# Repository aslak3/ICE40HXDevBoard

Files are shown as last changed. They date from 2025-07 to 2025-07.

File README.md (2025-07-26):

# ICE40HXDevBoard: an expandable iCE40HX4K development board

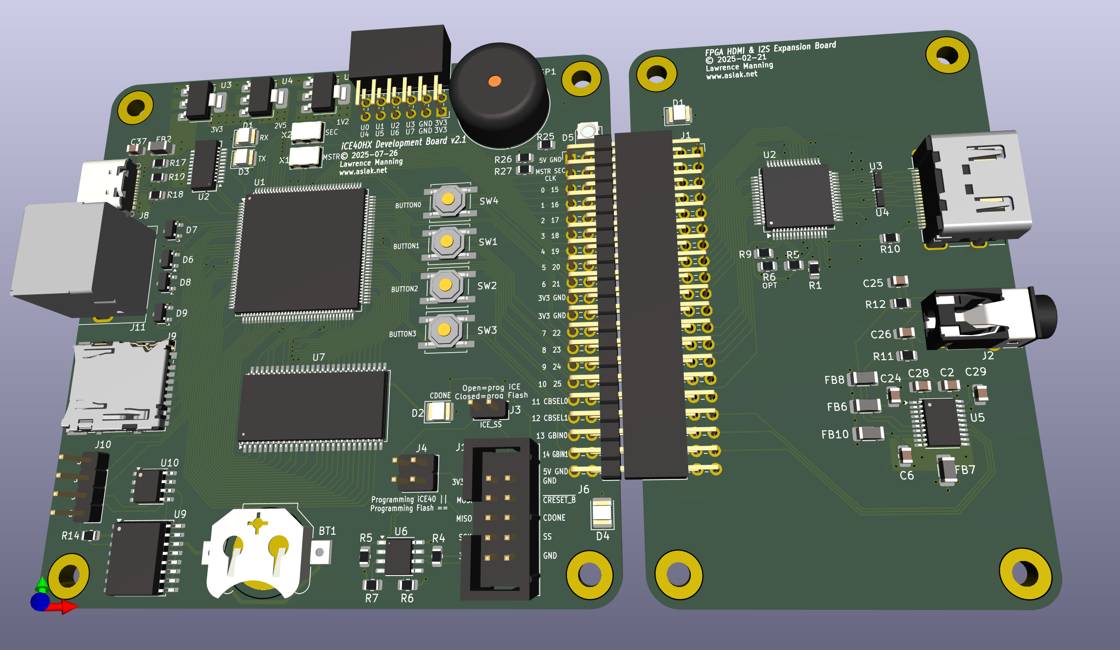
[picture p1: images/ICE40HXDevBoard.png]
ICE40HXDevBoard PCB


## Features

The specification for this development board is as follows:

* [iCE40HX4K](https://www.latticesemi.com/view_document?document_id=49312) in
144 pin QFP
  * [N25Q032A](https://docs.rs-online.com/0866/0900766b80f7f8ab.pdf) 32 Mbit SPI flash
* Space for two 5mm x 3mm oscillators
* [W9825G6KH](https://www.mouser.co.uk/datasheet/2/949/w9825g6kh_a04-1489735.pdf) 4M x 4 Banks x 16 bits SDRAM (32 MByte)
* PS/2 port with two channels for a mouse and keyboard
* I2C:
  * [DS3231M](https://www.analog.com/media/en/technical-documentation/data-sheets/ds3231m.pdf) RTC
  * [AT24C64](https://ww1.microchip.com/downloads/en/devicedoc/doc0336.pdf) EEPROM
  * Header for I2C connections
* RGB LED
* 4 buttons
* Buzzer
* [FT231XS](https://ftdichip.com/wp-content/uploads/2024/05/DS_FT231X.pdf) USB to UART converter with USB-C socket doubling up as the source of 5V power
* [MicroSDCard](https://en.wikipedia.org/wiki/SD_card) slot
* [PMOD](https://en.wikipedia.org/wiki/Pmod_Interface) header
* 40 pin expansion:
  * 3.3V and 5V power, 27 general purpose IO, 2 clock pins, shared I2C bus

A [schematic](ICE40HXDevBoard.pdf) is included here, along with the
[KiCAD](https://www.kicad.org) data files, whcih are in KiCAD 6 format.

## HDMI expansion card features

An expansion card featuring HDMI and I2S output on a 3.5mm jack has been built:

* [TFP410PAP](https://www.ti.com/lit/ds/symlink/tfp410.pdf) HDMI transmitter
  * Full size HDMI connector
* [PCM5100A](https://www.ti.com/lit/ds/symlink/pcm5100a.pdf) I2S DAC
  * 3.5mm stereo jack

## VGA expansion card features

A further, unbuilt, expansion card has been designed for VGA output:

* [ADV7123](https://www.analog.com/media/en/technical-documentation/data-sheets/ADV7123.pdf) RGB DAC
* [PCM5100A](https://www.ti.com/lit/ds/symlink/pcm5100a.pdf) I2S DAC
  * 3.5mm stereo jack

## PCB design

The PCBs are 4 layer boards.  My boards were manufactured by
[JLCPCB](https://www.jlcpcb.com).

## Using

The jumper mechanism to route the SPI signals which carry the configuration data
from the programmer was borrowed directly from the [Lattice’s iCE40 UltraPlus
Breakout Board](https://www.latticesemi.com/view_document?document_id=51987).

Any iCE40 compatible programmer should be useable. I built my own, out of a Pi
Pico, the software for which is documented in [another
repo](https://github.com/aslak3/spi-flasher). The programmer has been used to
program both the attached flash and the FPGA directly.

The header is a IDC10 in 100mil pitch. For the pinout refer to the schematic.

## Possible gotchas

The design of the FPGA board is a tweaked version of the build I have on my bench, since it has some issues:

* The PMOD pinning was backwards.
* The PS/2 port lacked clamping diodes due to the FPGA's intolerance of 5V signals from the PS/2 device. Remarkably I see no problems with my board, but it is not correct not having diodes to clamp the PS/2 data and clock lines to 3.3V.

The following features have not been tested yet:

* The MicroSDCard slot
* The SDRAM
* The I2C RTC
* The I2S DAC

## Blog

The best place to learn about this board is undoubtably [my
blog](https://www.aslak.net/).

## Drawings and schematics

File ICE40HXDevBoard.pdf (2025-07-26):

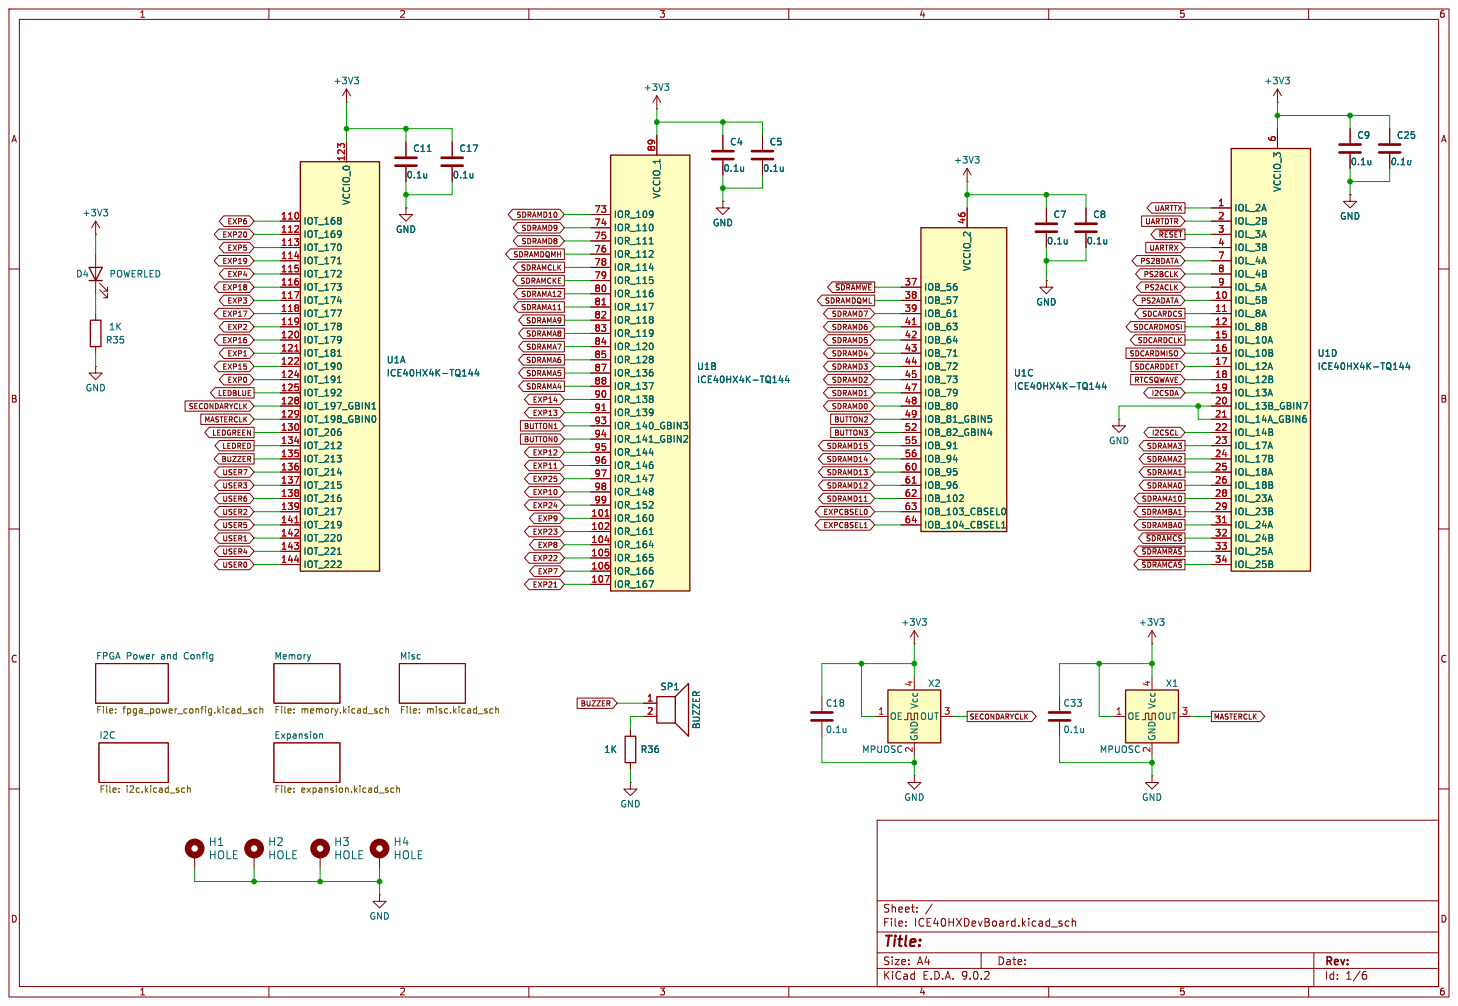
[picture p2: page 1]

Id: 1/6 Title: File: ICE40HXDevBoard.kicad_sch Sheet: / FPGA Power and Config File: fpga_power_config.kicad_sch

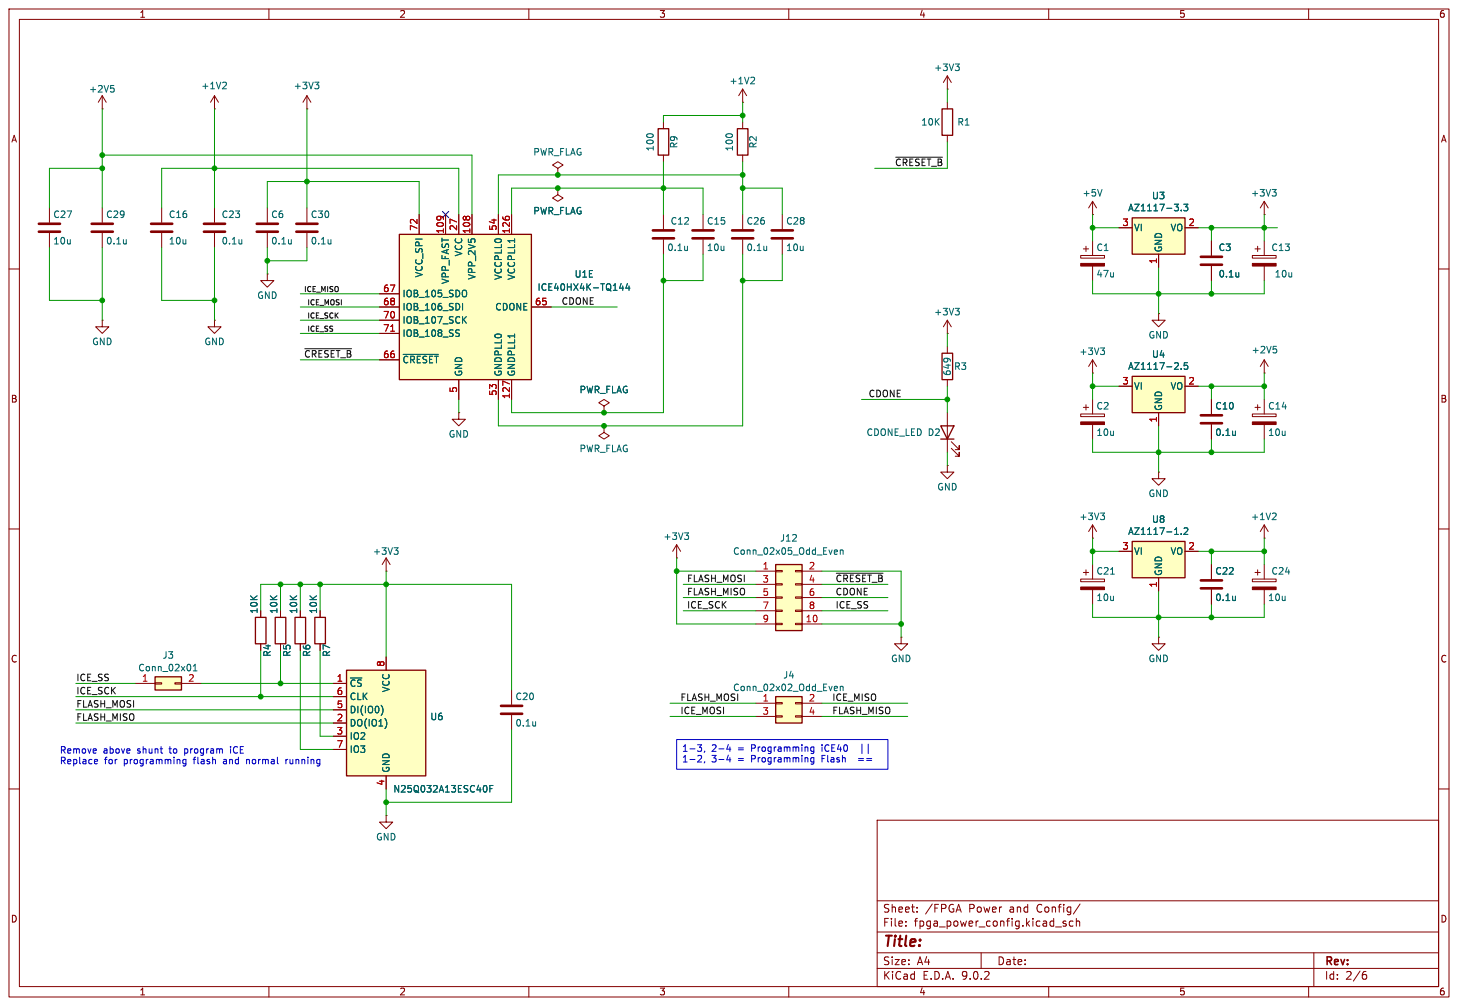
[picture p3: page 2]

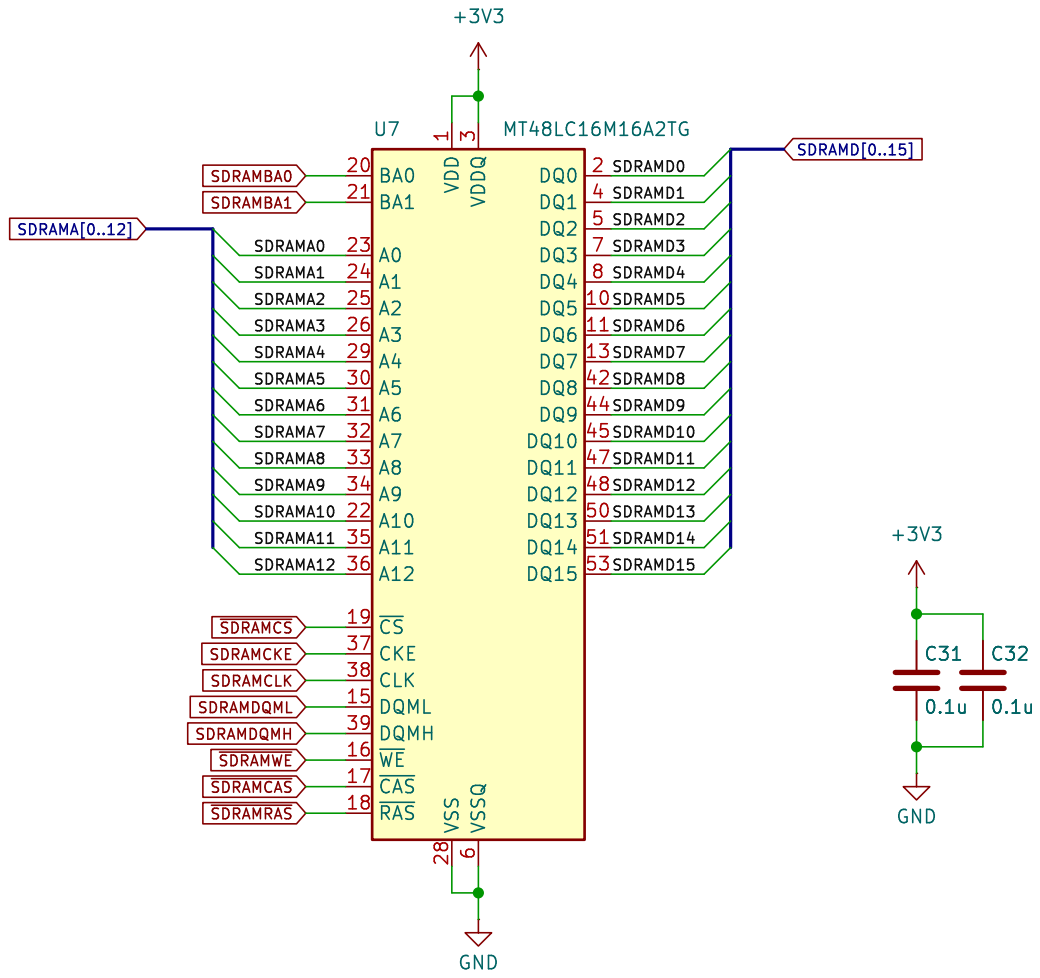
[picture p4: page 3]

SDRAMBA1 SDRAMBA0 SDRAMDQML ~{SDRAMCAS} ~{SDRAMWE} ~{SDRAMRAS} SDRAMDQMH

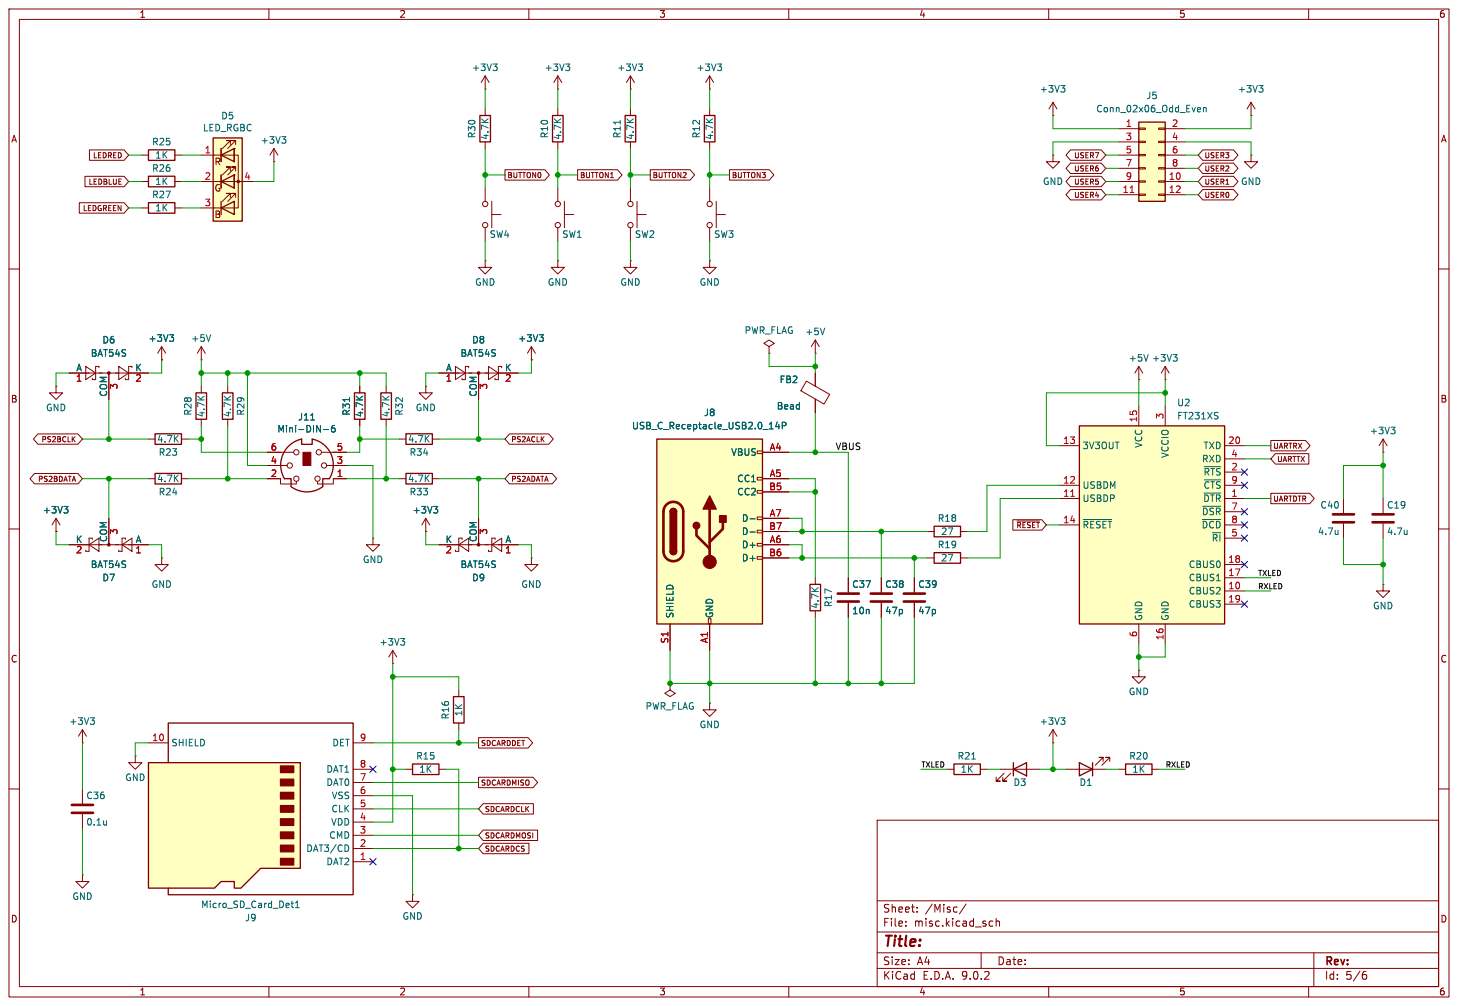
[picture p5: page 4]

3 GND 16 TXD 20 RXD 4 ~{RTS}2 ~{CTS}9 ~{DTR}1 ~{DSR}7 ~{DCD}8 ~{RI}5 CBUS0 18 CBUS1 17 CBUS2 10 CBUS3 19 U2 FT231XS R15

Id: 5/6 Title: File: misc.kicad_sch Sheet: /Misc/

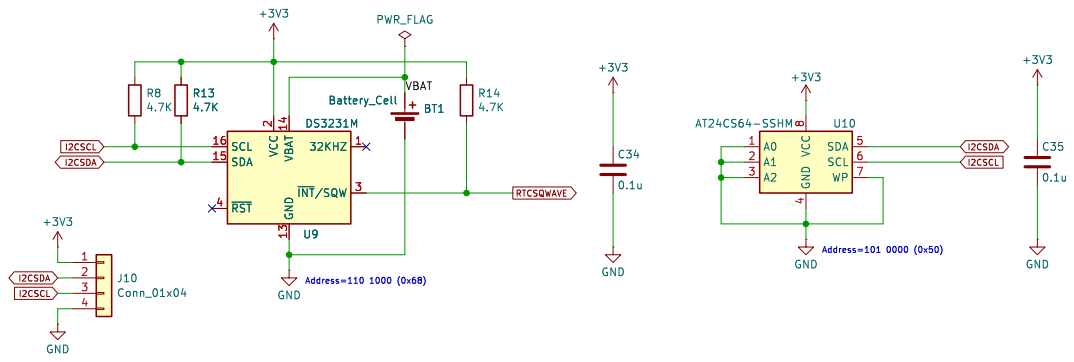
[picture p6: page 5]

4 SDA 5 SCL 6 WP 7 AT24CS64-SSHM U10 BT1 Battery_Cell PWR_FLAG

Id: 6/6 Title: File: i2c.kicad_sch Sheet: /I2C/

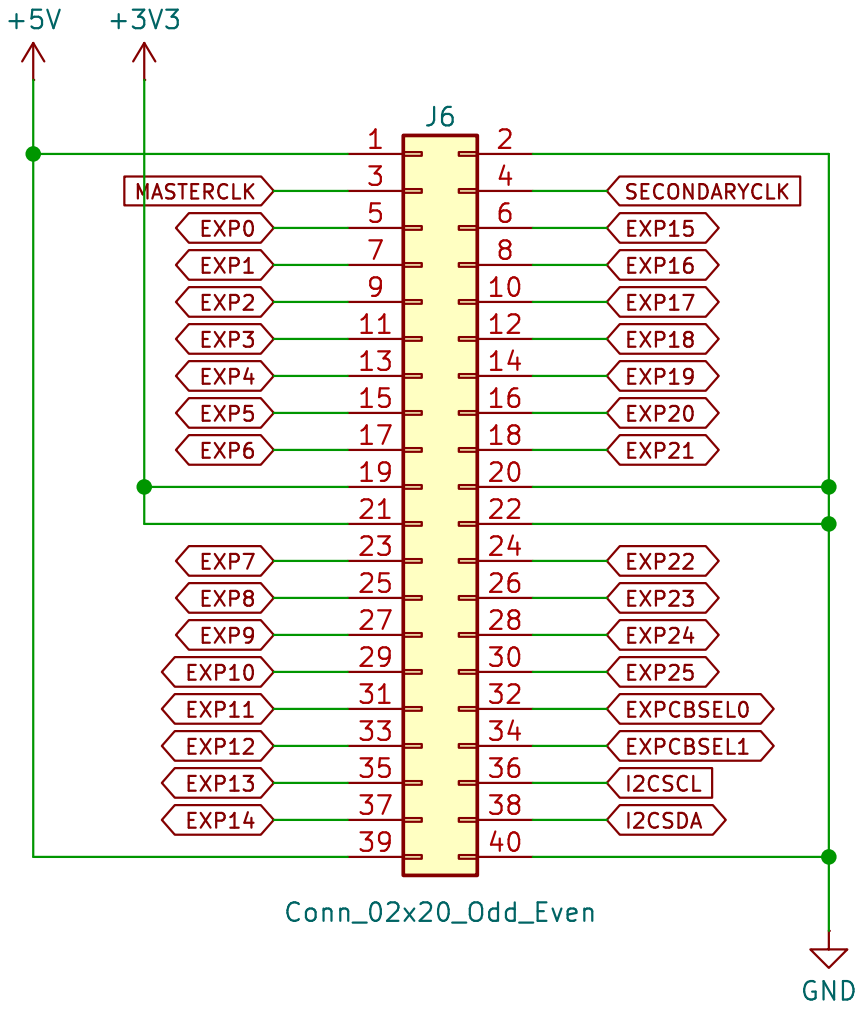
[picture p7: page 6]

Id: 6/6 Title: File: expansion.kicad_sch Sheet: /Expansion/

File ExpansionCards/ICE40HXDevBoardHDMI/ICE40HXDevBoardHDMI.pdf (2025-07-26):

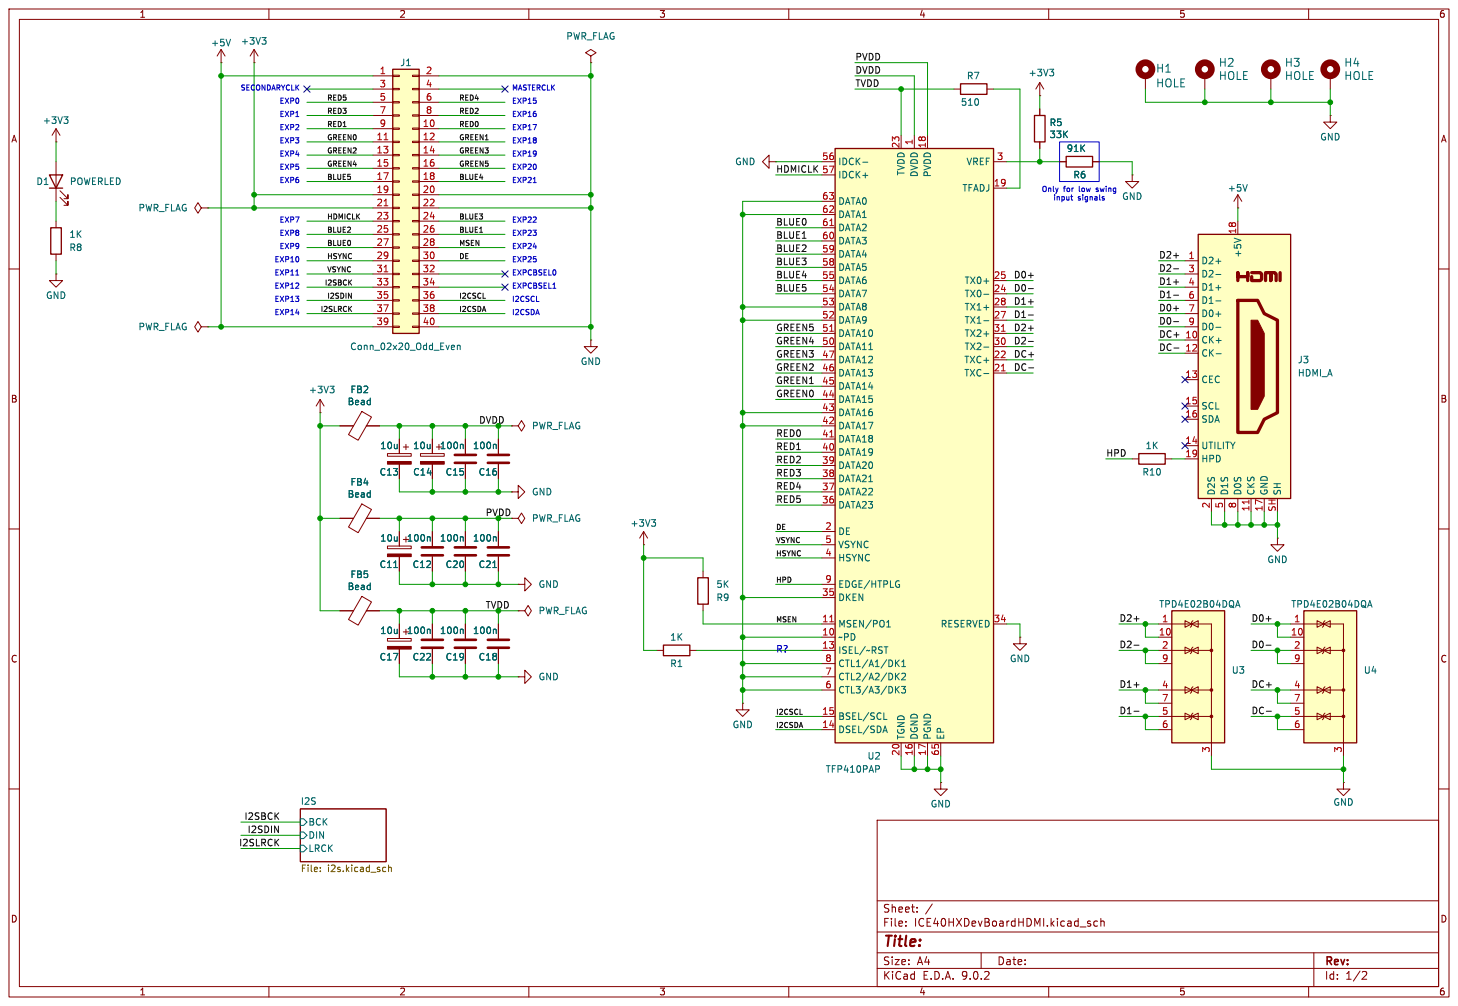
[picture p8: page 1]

1 DGND 16 PVDD 18 PGND 17 EP 65 VREF 3 TFADJ 19 TX0+ 25 TX0- 24 TX1+ 28 TX1- 27 TX2+ 31 TX2- 30 TXC+ 22 TXC- 21 RESERVED 34 U2 TFP410PAP

8 CKS 11 GND 17 SH SH

Id: 1/2 Title: File: ICE40HXDevBoardHDMI.kicad_sch Sheet: / BCK DIN

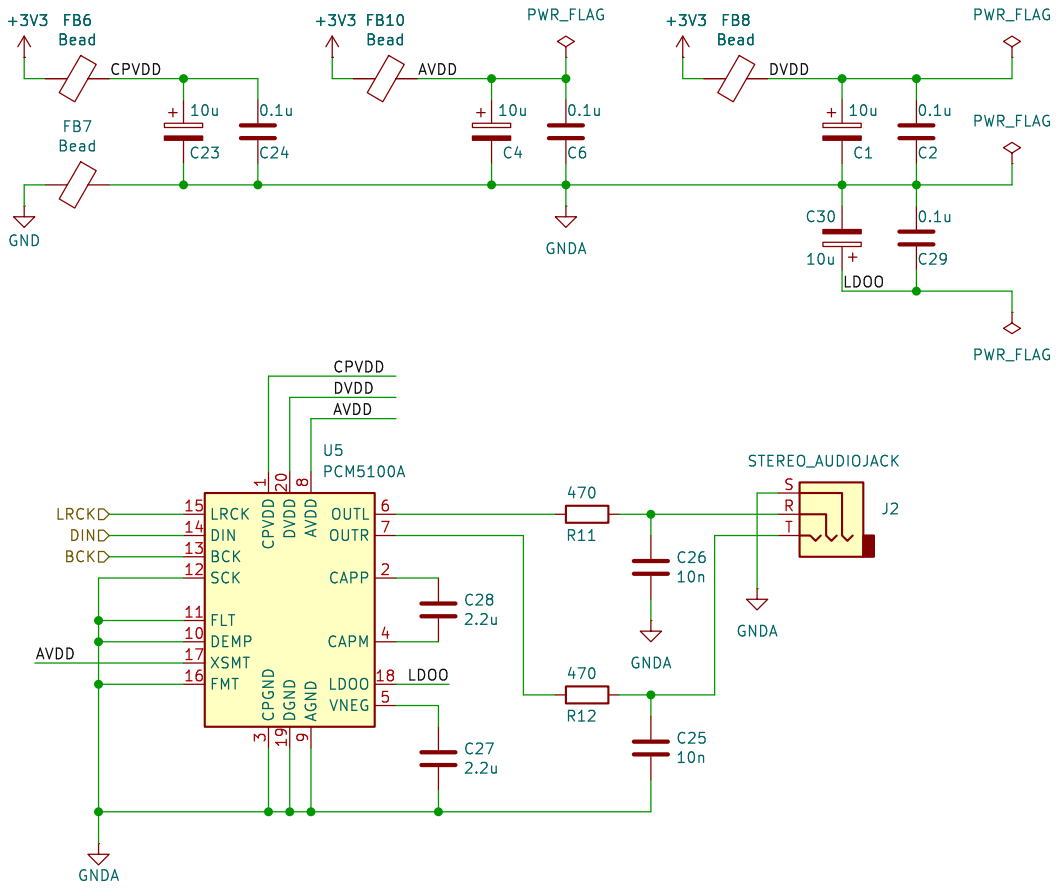
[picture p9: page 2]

9 OUTL 6 OUTR 7 CAPP 2 CAPM 4

Id: 2/2 Title: File: i2s.kicad_sch Sheet: /I2S/

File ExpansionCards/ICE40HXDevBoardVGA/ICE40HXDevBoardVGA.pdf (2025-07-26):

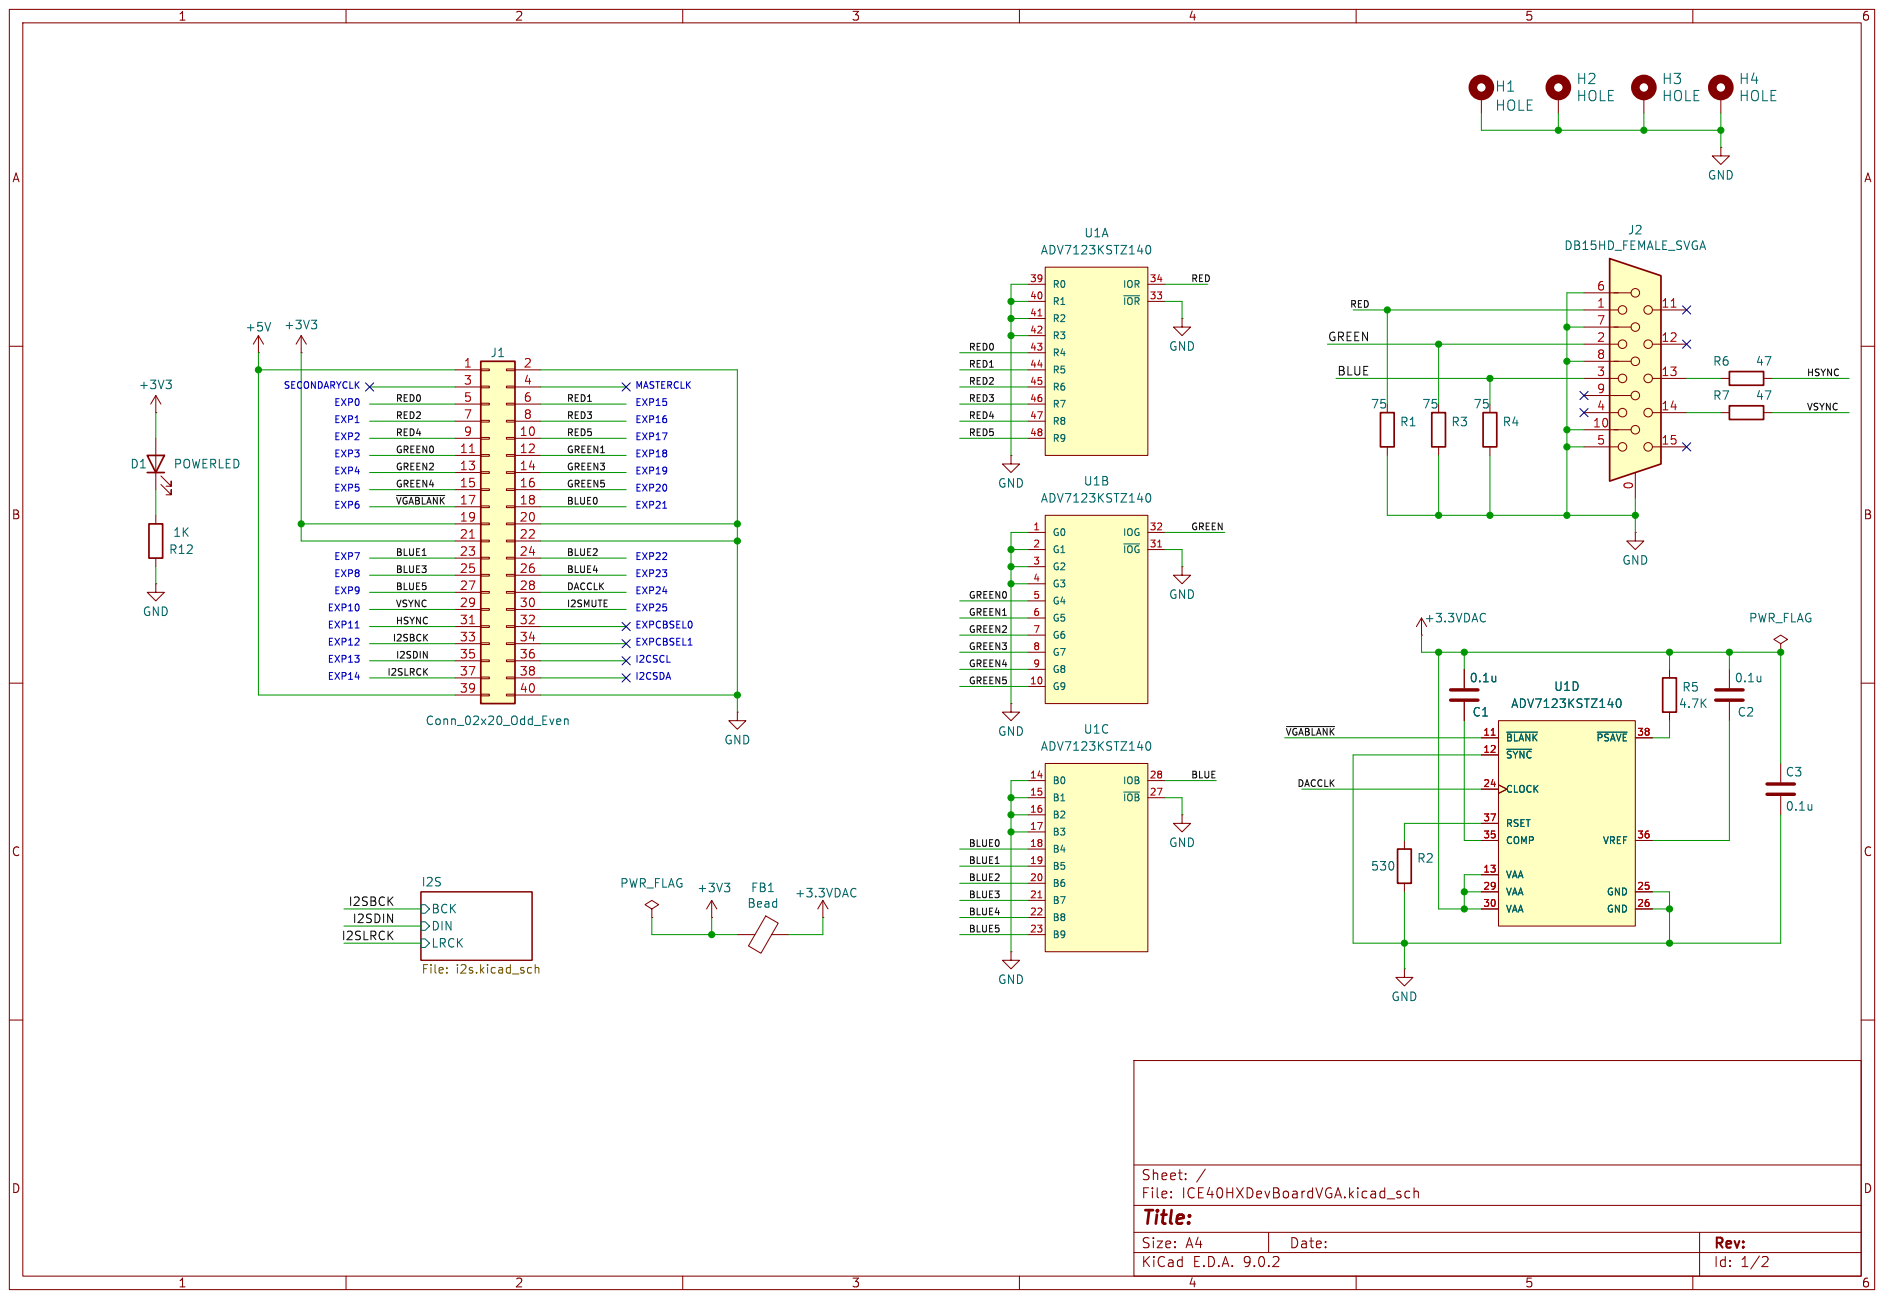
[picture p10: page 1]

Id: 1/2 Title: File: ICE40HXDevBoardVGA.kicad_sch Sheet: / BCK DIN

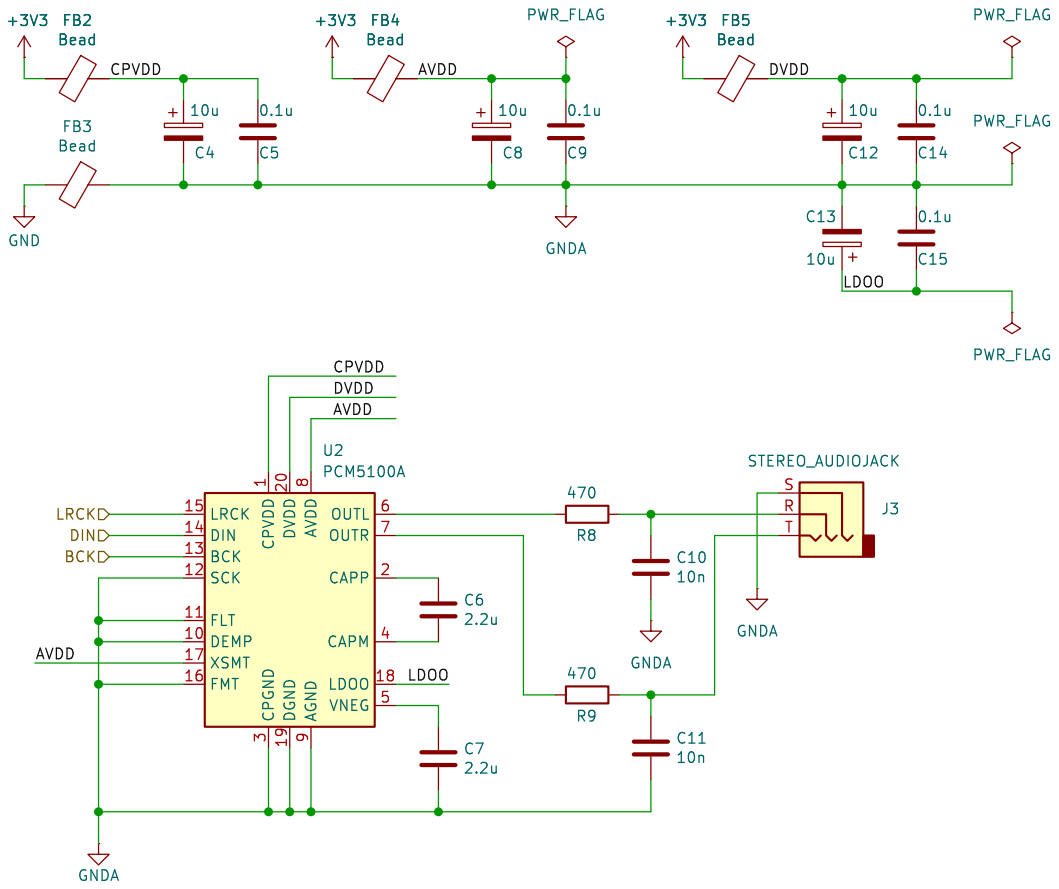
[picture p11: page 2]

9 OUTL 6 OUTR 7 CAPP 2 CAPM 4

Id: 2/2 Title: File: i2s.kicad_sch Sheet: /I2S/

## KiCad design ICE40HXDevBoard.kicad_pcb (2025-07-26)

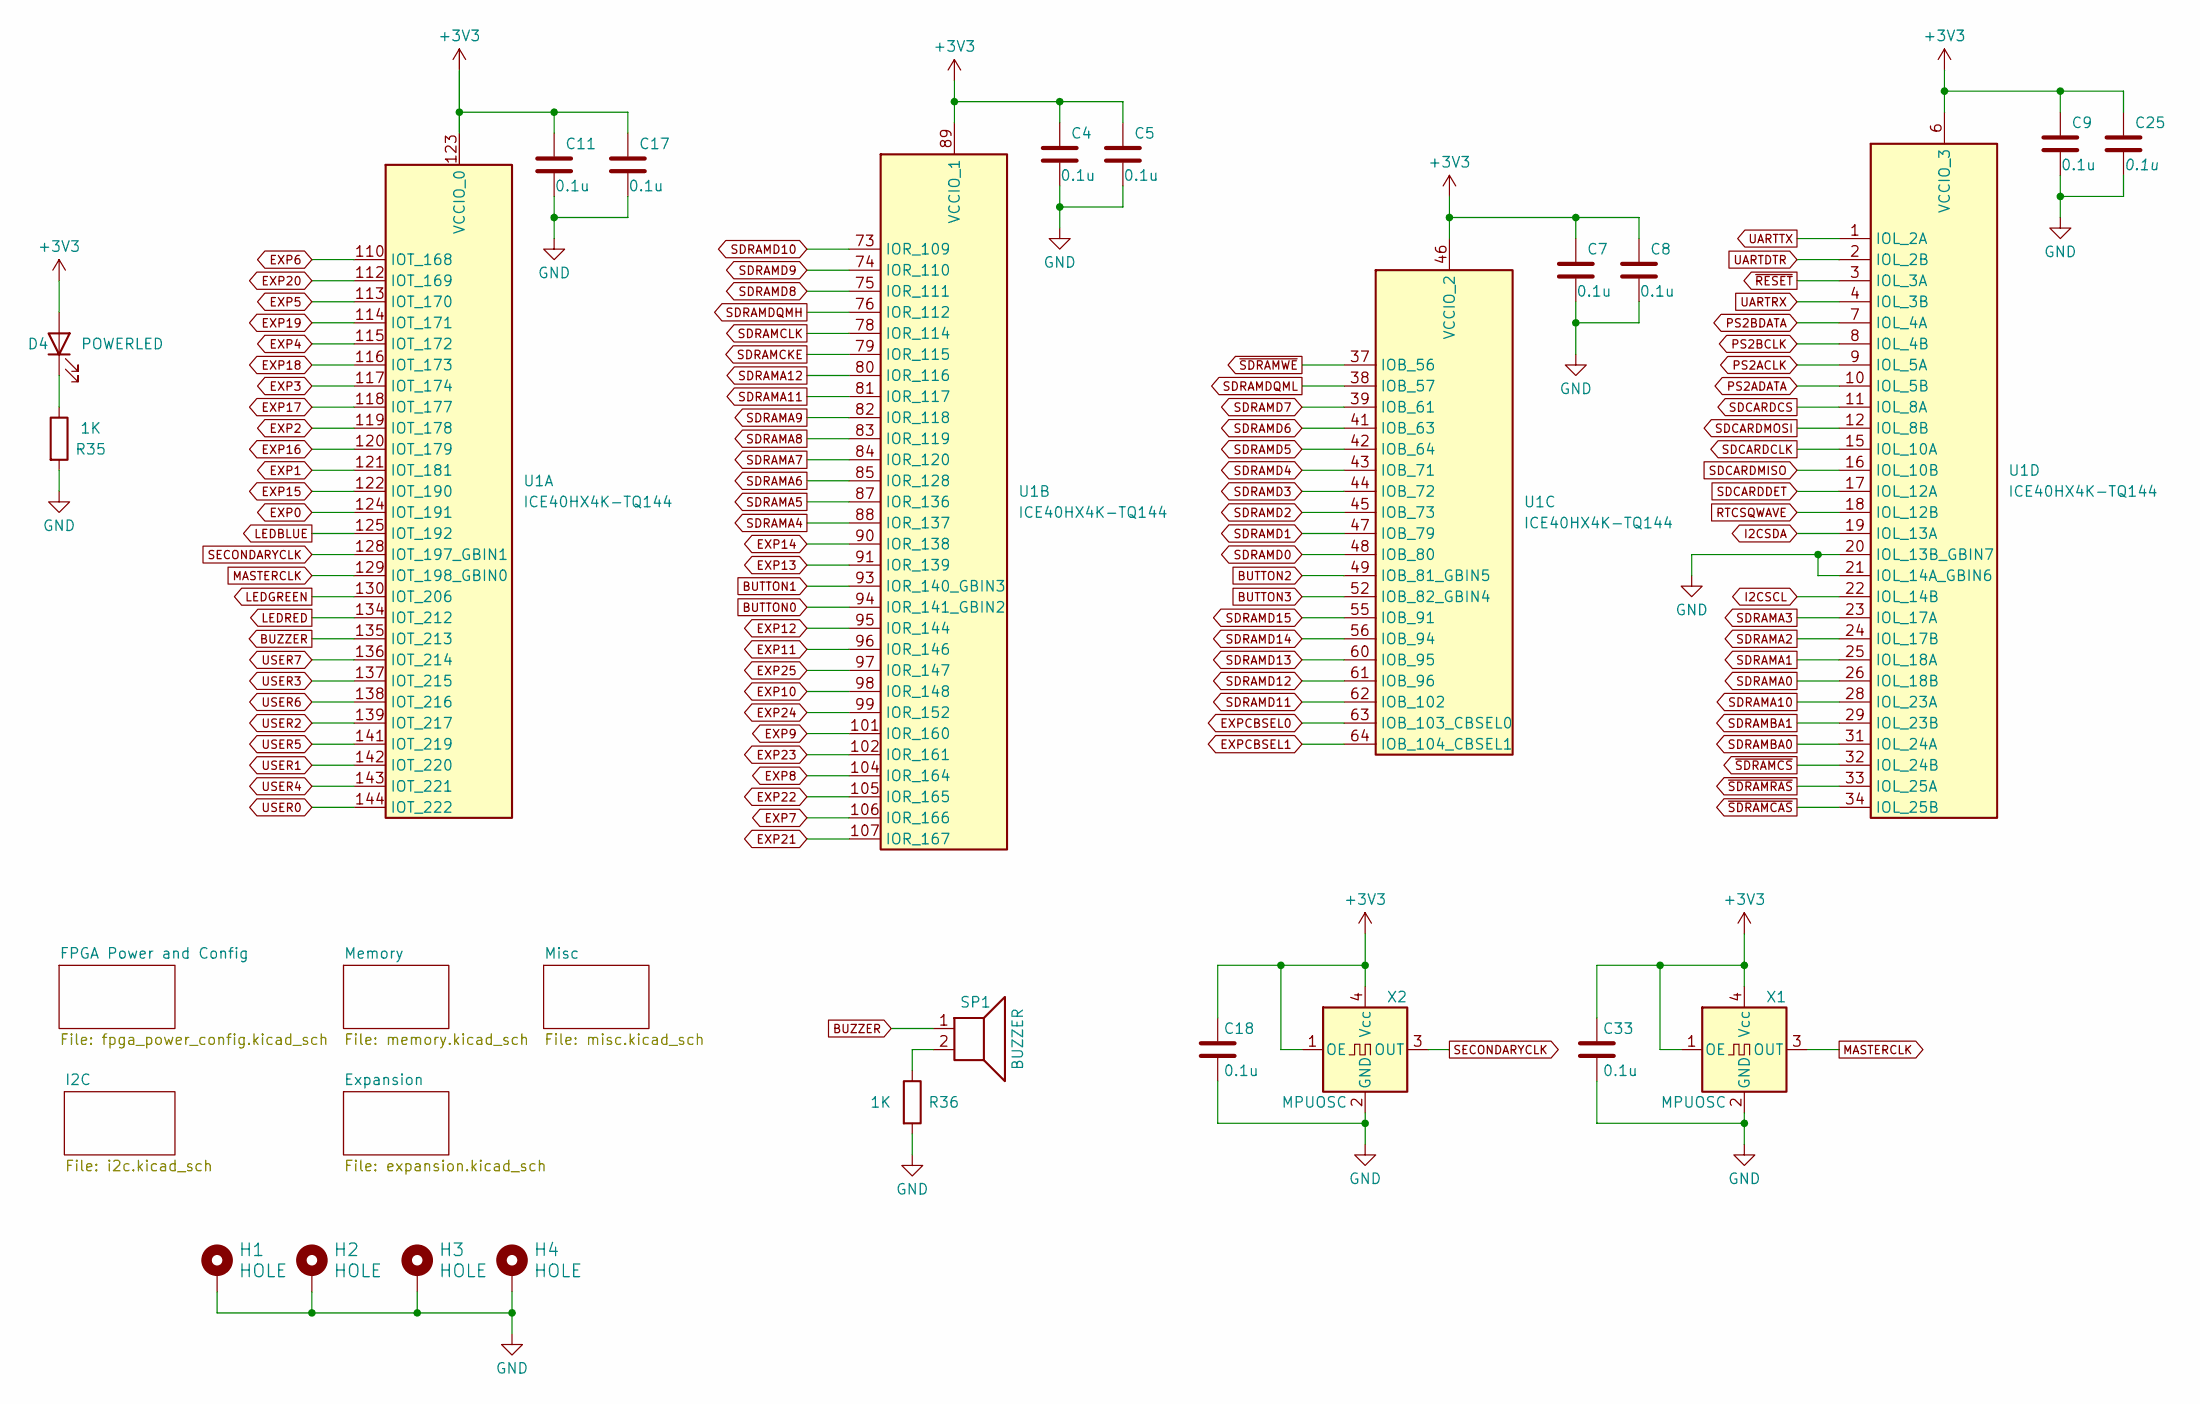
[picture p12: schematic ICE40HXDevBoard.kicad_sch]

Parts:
C4, C5, C7, C8, C9, C11, C17, C18, C25, C33: 0.1u; C_0805_2012Metric
D4: POWERLED; LED_1210_3225Metric
H1, H2, H3, H4: HOLE; MountingHole_3.2mm_M3_Pad
R35, R36: 1K; R_0805_2012Metric
SP1: BUZZER; Buzzer_15x7.5RM7.6
U1: ICE40HX4K-TQ144; TQFP-144_20x20mm_P0.5mm
X1, X2: MPUOSC; Oscillator_SMD_SeikoEpson_SG8002LB-4Pin_5.0x3.2mm

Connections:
+3V3: C4.1, C5.1, C7.1, C8.1, C9.1, C11.1, C17.1, C18.1, C25.1, C33.1, D4.2 (A), U1.6 (VCCIO_3), U1.30 (VCCIO_3), U1.46 (VCCIO_2), U1.57 (VCCIO_2), U1.89 (VCCIO_1), U1.100 (VCCIO_1), U1.123 (VCCIO_0), U1.131 (VCCIO_0), X1.1 (OE), X1.4 (Vcc), X2.1 (OE), X2.4 (Vcc); also elsewhere on the board
BUTTON0: U1.94 (IOR_141_GBIN2); also elsewhere on the board
BUTTON1: U1.93 (IOR_140_GBIN3); also elsewhere on the board
BUTTON2: U1.49 (IOB_81_GBIN5); also elsewhere on the board
BUTTON3: U1.52 (IOB_82_GBIN4); also elsewhere on the board
BUZZER: SP1.1, U1.135 (IOT_213)
EXP0: U1.124 (IOT_191); also elsewhere on the board
EXP1: U1.121 (IOT_181); also elsewhere on the board
EXP2: U1.119 (IOT_178); also elsewhere on the board
EXP3: U1.117 (IOT_174); also elsewhere on the board
EXP4: U1.115 (IOT_172); also elsewhere on the board
EXP5: U1.113 (IOT_170); also elsewhere on the board
EXP6: U1.110 (IOT_168); also elsewhere on the board
EXP7: U1.106 (IOR_166); also elsewhere on the board
EXP8: U1.104 (IOR_164); also elsewhere on the board
EXP9: U1.101 (IOR_160); also elsewhere on the board
EXP10: U1.98 (IOR_148); also elsewhere on the board
EXP11: U1.96 (IOR_146); also elsewhere on the board
EXP12: U1.95 (IOR_144); also elsewhere on the board
EXP13: U1.91 (IOR_139); also elsewhere on the board
EXP14: U1.90 (IOR_138); also elsewhere on the board
EXP15: U1.122 (IOT_190); also elsewhere on the board
EXP16: U1.120 (IOT_179); also elsewhere on the board
EXP17: U1.118 (IOT_177); also elsewhere on the board
EXP18: U1.116 (IOT_173); also elsewhere on the board
EXP19: U1.114 (IOT_171); also elsewhere on the board
EXP20: U1.112 (IOT_169); also elsewhere on the board
EXP21: U1.107 (IOR_167); also elsewhere on the board
EXP22: U1.105 (IOR_165); also elsewhere on the board
EXP23: U1.102 (IOR_161); also elsewhere on the board
EXP24: U1.99 (IOR_152); also elsewhere on the board
EXP25: U1.97 (IOR_147); also elsewhere on the board
EXPCBSEL0: U1.63 (IOB_103_CBSEL0); also elsewhere on the board
EXPCBSEL1: U1.64 (IOB_104_CBSEL1); also elsewhere on the board
GND: C4.2, C5.2, C7.2, C8.2, C9.2, C11.2, C17.2, C18.2, C25.2, C33.2, H1.1, H2.1, H3.1, H4.1, R35.2, R36.2, U1.20 (IOL_13B_GBIN7), U1.21 (IOL_14A_GBIN6), X1.2 (GND), X2.2 (GND); also elsewhere on the board
I2CSCL: U1.22 (IOL_14B); also elsewhere on the board
I2CSDA: U1.19 (IOL_13A); also elsewhere on the board
LEDBLUE: U1.125 (IOT_192); also elsewhere on the board
LEDGREEN: U1.130 (IOT_206); also elsewhere on the board
LEDRED: U1.134 (IOT_212); also elsewhere on the board
MASTERCLK: U1.129 (IOT_198_GBIN0), X1.3 (OUT); also elsewhere on the board
unnamed: D4.1 (K), R35.1
unnamed: R36.1, SP1.2
PS2ACLK: U1.9 (IOL_5A); also elsewhere on the board
PS2ADATA: U1.10 (IOL_5B); also elsewhere on the board
PS2BCLK: U1.8 (IOL_4B); also elsewhere on the board
PS2BDATA: U1.7 (IOL_4A); also elsewhere on the board
RTCSQWAVE: U1.18 (IOL_12B); also elsewhere on the board
SDCARDCLK: U1.15 (IOL_10A); also elsewhere on the board
SDCARDCS: U1.11 (IOL_8A); also elsewhere on the board
SDCARDDET: U1.17 (IOL_12A); also elsewhere on the board
SDCARDMISO: U1.16 (IOL_10B); also elsewhere on the board
SDCARDMOSI: U1.12 (IOL_8B); also elsewhere on the board
SDRAMA0: U1.26 (IOL_18B); also elsewhere on the board
SDRAMA1: U1.25 (IOL_18A); also elsewhere on the board
SDRAMA2: U1.24 (IOL_17B); also elsewhere on the board
SDRAMA3: U1.23 (IOL_17A); also elsewhere on the board
SDRAMA4: U1.88 (IOR_137); also elsewhere on the board
SDRAMA5: U1.87 (IOR_136); also elsewhere on the board
SDRAMA6: U1.85 (IOR_128); also elsewhere on the board
SDRAMA7: U1.84 (IOR_120); also elsewhere on the board
SDRAMA8: U1.83 (IOR_119); also elsewhere on the board
SDRAMA9: U1.82 (IOR_118); also elsewhere on the board
SDRAMA10: U1.28 (IOL_23A); also elsewhere on the board
SDRAMA11: U1.81 (IOR_117); also elsewhere on the board
SDRAMA12: U1.80 (IOR_116); also elsewhere on the board
SDRAMBA0: U1.31 (IOL_24A); also elsewhere on the board
SDRAMBA1: U1.29 (IOL_23B); also elsewhere on the board
SDRAMCKE: U1.79 (IOR_115); also elsewhere on the board
SDRAMCLK: U1.78 (IOR_114); also elsewhere on the board
SDRAMD0: U1.48 (IOB_80); also elsewhere on the board
SDRAMD1: U1.47 (IOB_79); also elsewhere on the board
SDRAMD2: U1.45 (IOB_73); also elsewhere on the board
SDRAMD3: U1.44 (IOB_72); also elsewhere on the board
SDRAMD4: U1.43 (IOB_71); also elsewhere on the board
SDRAMD5: U1.42 (IOB_64); also elsewhere on the board
SDRAMD6: U1.41 (IOB_63); also elsewhere on the board
SDRAMD7: U1.39 (IOB_61); also elsewhere on the board
SDRAMD8: U1.75 (IOR_111); also elsewhere on the board
SDRAMD9: U1.74 (IOR_110); also elsewhere on the board
SDRAMD10: U1.73 (IOR_109); also elsewhere on the board
SDRAMD11: U1.62 (IOB_102); also elsewhere on the board
SDRAMD12: U1.61 (IOB_96); also elsewhere on the board
SDRAMD13: U1.60 (IOB_95); also elsewhere on the board
SDRAMD14: U1.56 (IOB_94); also elsewhere on the board
SDRAMD15: U1.55 (IOB_91); also elsewhere on the board
SDRAMDQMH: U1.76 (IOR_112); also elsewhere on the board
SDRAMDQML: U1.38 (IOB_57); also elsewhere on the board
SECONDARYCLK: U1.128 (IOT_197_GBIN1), X2.3 (OUT); also elsewhere on the board
UARTDTR: U1.2 (IOL_2B); also elsewhere on the board
UARTRX: U1.4 (IOL_3B); also elsewhere on the board
UARTTX: U1.1 (IOL_2A); also elsewhere on the board
USER0: U1.144 (IOT_222); also elsewhere on the board
USER1: U1.142 (IOT_220); also elsewhere on the board
USER2: U1.139 (IOT_217); also elsewhere on the board
USER3: U1.137 (IOT_215); also elsewhere on the board
USER4: U1.143 (IOT_221); also elsewhere on the board
USER5: U1.141 (IOT_219); also elsewhere on the board
USER6: U1.138 (IOT_216); also elsewhere on the board
USER7: U1.136 (IOT_214); also elsewhere on the board
~RESET: U1.3 (IOL_3A); also elsewhere on the board
~SDRAMCAS: U1.34 (IOL_25B); also elsewhere on the board
~SDRAMCS: U1.32 (IOL_24B); also elsewhere on the board
~SDRAMRAS: U1.33 (IOL_25A); also elsewhere on the board
~SDRAMWE: U1.37 (IOB_56); also elsewhere on the board

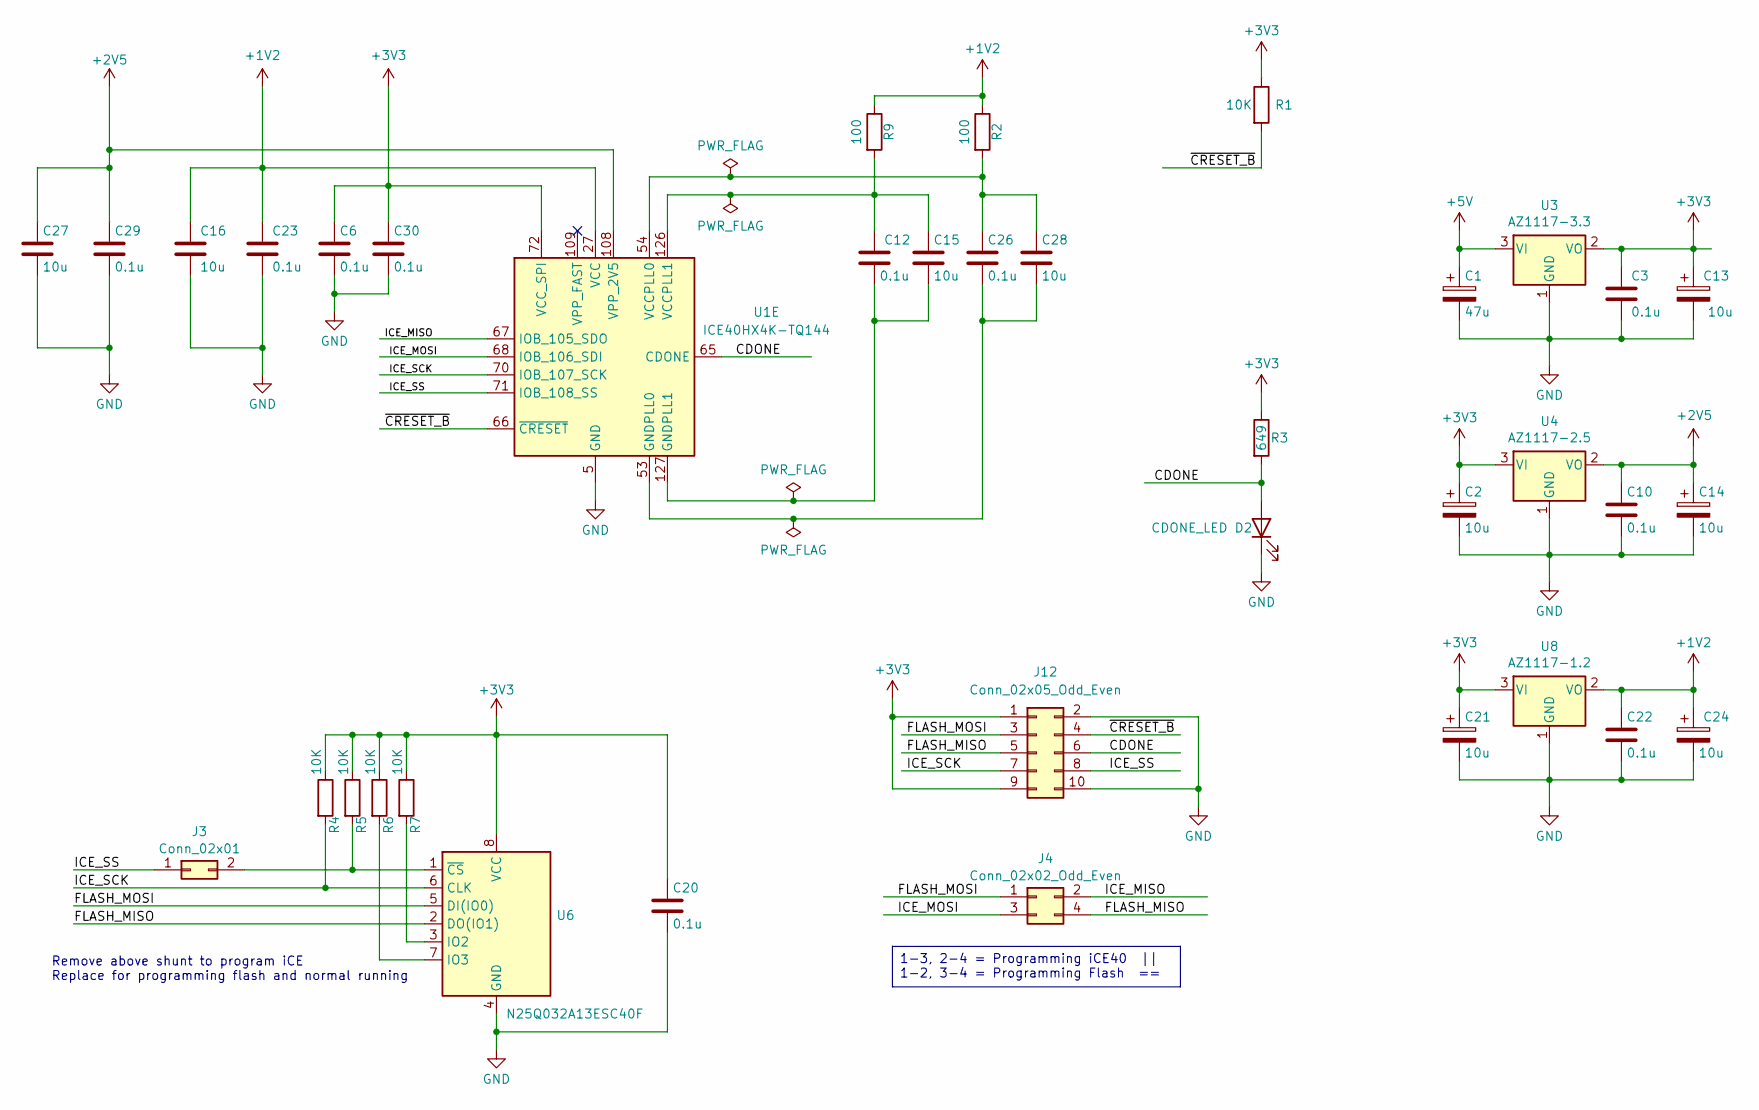
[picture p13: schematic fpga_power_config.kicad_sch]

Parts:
C1: 47u; CP_EIA-7343-15_Kemet-W
C2, C13, C14, C21, C24: 10u; CP_EIA-3216-10_Kemet-I
C3, C6, C10, C12, C20, C22, C23, C26, C29, C30: 0.1u; C_0805_2012Metric
C15, C16, C27, C28: 10u; C_0805_2012Metric
D2: CDONE_LED; LED_1210_3225Metric
J3: Conn_02x01; PinHeader_2x01_P2.54mm_Vertical
J4: Conn_02x02_Odd_Even; PinHeader_2x02_P2.54mm_Vertical
J12: Conn_02x05_Odd_Even; IDC-Header_2x05_P2.54mm_Vertical
R1, R4, R5, R6, R7: 10K; R_0805_2012Metric
R2, R9: 100; R_0805_2012Metric
R3: 649; R_0805_2012Metric
U1: ICE40HX4K-TQ144; TQFP-144_20x20mm_P0.5mm
U3: AZ1117-3.3; SOT-223-3_TabPin2
U4: AZ1117-2.5; SOT-223-3_TabPin2
U6: N25Q032A13ESC40F; SOP-8_3.9x4.9mm_P1.27mm
U8: AZ1117-1.2; SOT-223-3_TabPin2

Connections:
+1V2: C16.1, C22.1, C23.1, C24.1, R2.1, R9.1, U1.27 (VCC), U1.40 (VCC), U1.92 (VCC), U1.111 (VCC), U8.2 (VO)
+2V5: C10.1, C14.1, C27.1, C29.1, U1.108 (VPP_2V5), U4.2 (VO)
+3V3: C2.1, C3.1, C6.1, C13.1, C20.1, C21.1, C30.1, J12.1, J12.9, R1.1, R3.1, R4.1, R5.1, R6.1, R7.1, U1.72 (VCC_SPI), U3.2 (VO), U4.3 (VI), U6.8 (VCC), U8.3 (VI); also elsewhere on the board
+5V: C1.1, U3.3 (VI); also elsewhere on the board
/FPGA Power and Config/CDONE: D2.2 (A), J12.6, R3.2, U1.65 (CDONE)
/FPGA Power and Config/FLASH_MISO: J4.4, J12.5, U6.2 (DO(IO1))
/FPGA Power and Config/FLASH_MOSI: J4.1, J12.3, U6.5 (DI(IO0))
/FPGA Power and Config/ICE_MISO: J4.2, U1.67 (IOB_105_SDO)
/FPGA Power and Config/ICE_MOSI: J4.3, U1.68 (IOB_106_SDI)
/FPGA Power and Config/ICE_SCK: J12.7, R4.2, U1.70 (IOB_107_SCK), U6.6 (CLK)
/FPGA Power and Config/ICE_SS: J3.1, J12.8, U1.71 (IOB_108_SS)
/FPGA Power and Config/~CRESET_B: J12.4, R1.2, U1.66 (~CRESET)
GND: C1.2, C2.2, C3.2, C6.2, C10.2, C13.2, C14.2, C16.2, C20.2, C21.2, C22.2, C23.2, C24.2, C27.2, C29.2, C30.2, D2.1 (K), J12.2, J12.10, U1.5 (GND), U1.13 (GND), U1.14 (GND), U1.59 (GND), U1.69 (GND), U1.86 (GND), U1.103 (GND), U1.132 (GND), U1.140 (GND), U3.1 (GND), U4.1 (GND), U6.4 (GND), U8.1 (GND); also elsewhere on the board
unnamed: J3.2, R5.2, U6.1 (~CS)
unnamed: C26.2, C28.2, U1.53 (GNDPLL0)
unnamed: C12.2, C15.2, U1.127 (GNDPLL1)
unnamed: C26.1, C28.1, R2.2, U1.54 (VCCPLL0)
unnamed: C12.1, C15.1, R9.2, U1.126 (VCCPLL1)
unnamed: R7.2, U6.3 (IO2)
unnamed: R6.2, U6.7 (IO3)

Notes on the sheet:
Remove above shunt to program iCE Replace for programming flash and normal running
1-3, 2-4 = Programming iCE40 || 1-2, 3-4 = Programming Flash ==

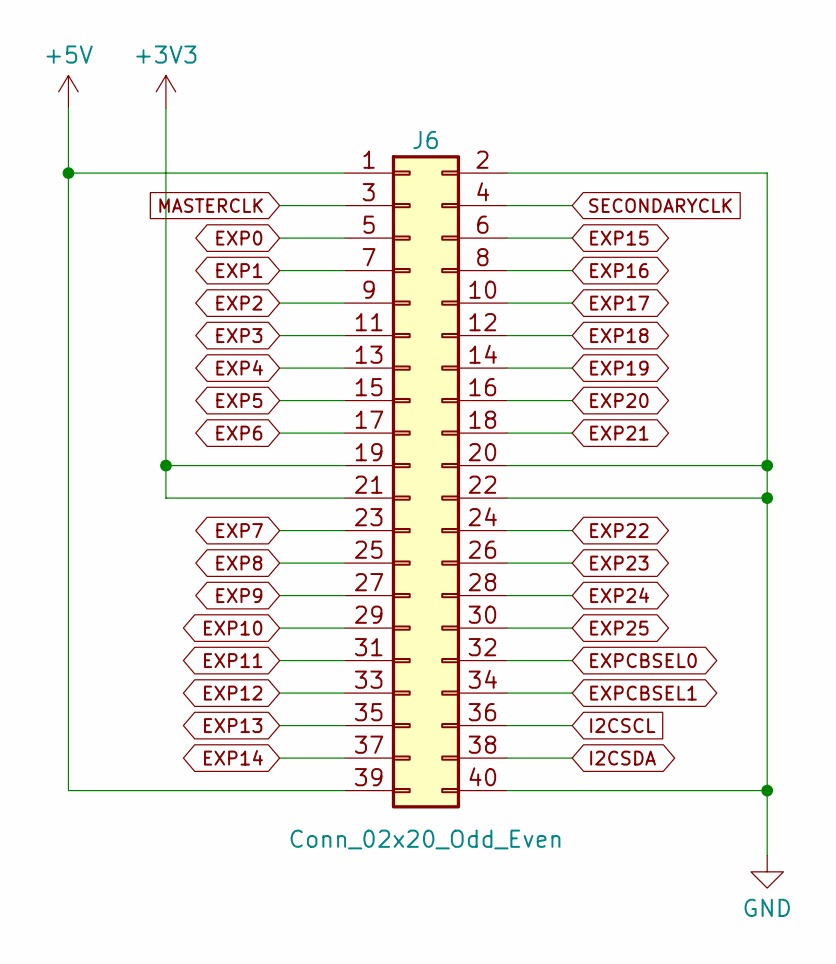
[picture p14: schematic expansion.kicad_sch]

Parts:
J6: Conn_02x20_Odd_Even; PinHeader_2x20_P2.54mm_Horizontal

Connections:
+3V3: J6.19, J6.21; also elsewhere on the board
+5V: J6.1, J6.39; also elsewhere on the board
EXP0: J6.5; also elsewhere on the board
EXP1: J6.7; also elsewhere on the board
EXP2: J6.9; also elsewhere on the board
EXP3: J6.11; also elsewhere on the board
EXP4: J6.13; also elsewhere on the board
EXP5: J6.15; also elsewhere on the board
EXP6: J6.17; also elsewhere on the board
EXP7: J6.23; also elsewhere on the board
EXP8: J6.25; also elsewhere on the board
EXP9: J6.27; also elsewhere on the board
EXP10: J6.29; also elsewhere on the board
EXP11: J6.31; also elsewhere on the board
EXP12: J6.33; also elsewhere on the board
EXP13: J6.35; also elsewhere on the board
EXP14: J6.37; also elsewhere on the board
EXP15: J6.6; also elsewhere on the board
EXP16: J6.8; also elsewhere on the board
EXP17: J6.10; also elsewhere on the board
EXP18: J6.12; also elsewhere on the board
EXP19: J6.14; also elsewhere on the board
EXP20: J6.16; also elsewhere on the board
EXP21: J6.18; also elsewhere on the board
EXP22: J6.24; also elsewhere on the board
EXP23: J6.26; also elsewhere on the board
EXP24: J6.28; also elsewhere on the board
EXP25: J6.30; also elsewhere on the board
EXPCBSEL0: J6.32; also elsewhere on the board
EXPCBSEL1: J6.34; also elsewhere on the board
GND: J6.2, J6.20, J6.22, J6.40; also elsewhere on the board
I2CSCL: J6.36; also elsewhere on the board
I2CSDA: J6.38; also elsewhere on the board
MASTERCLK: J6.3; also elsewhere on the board
SECONDARYCLK: J6.4; also elsewhere on the board

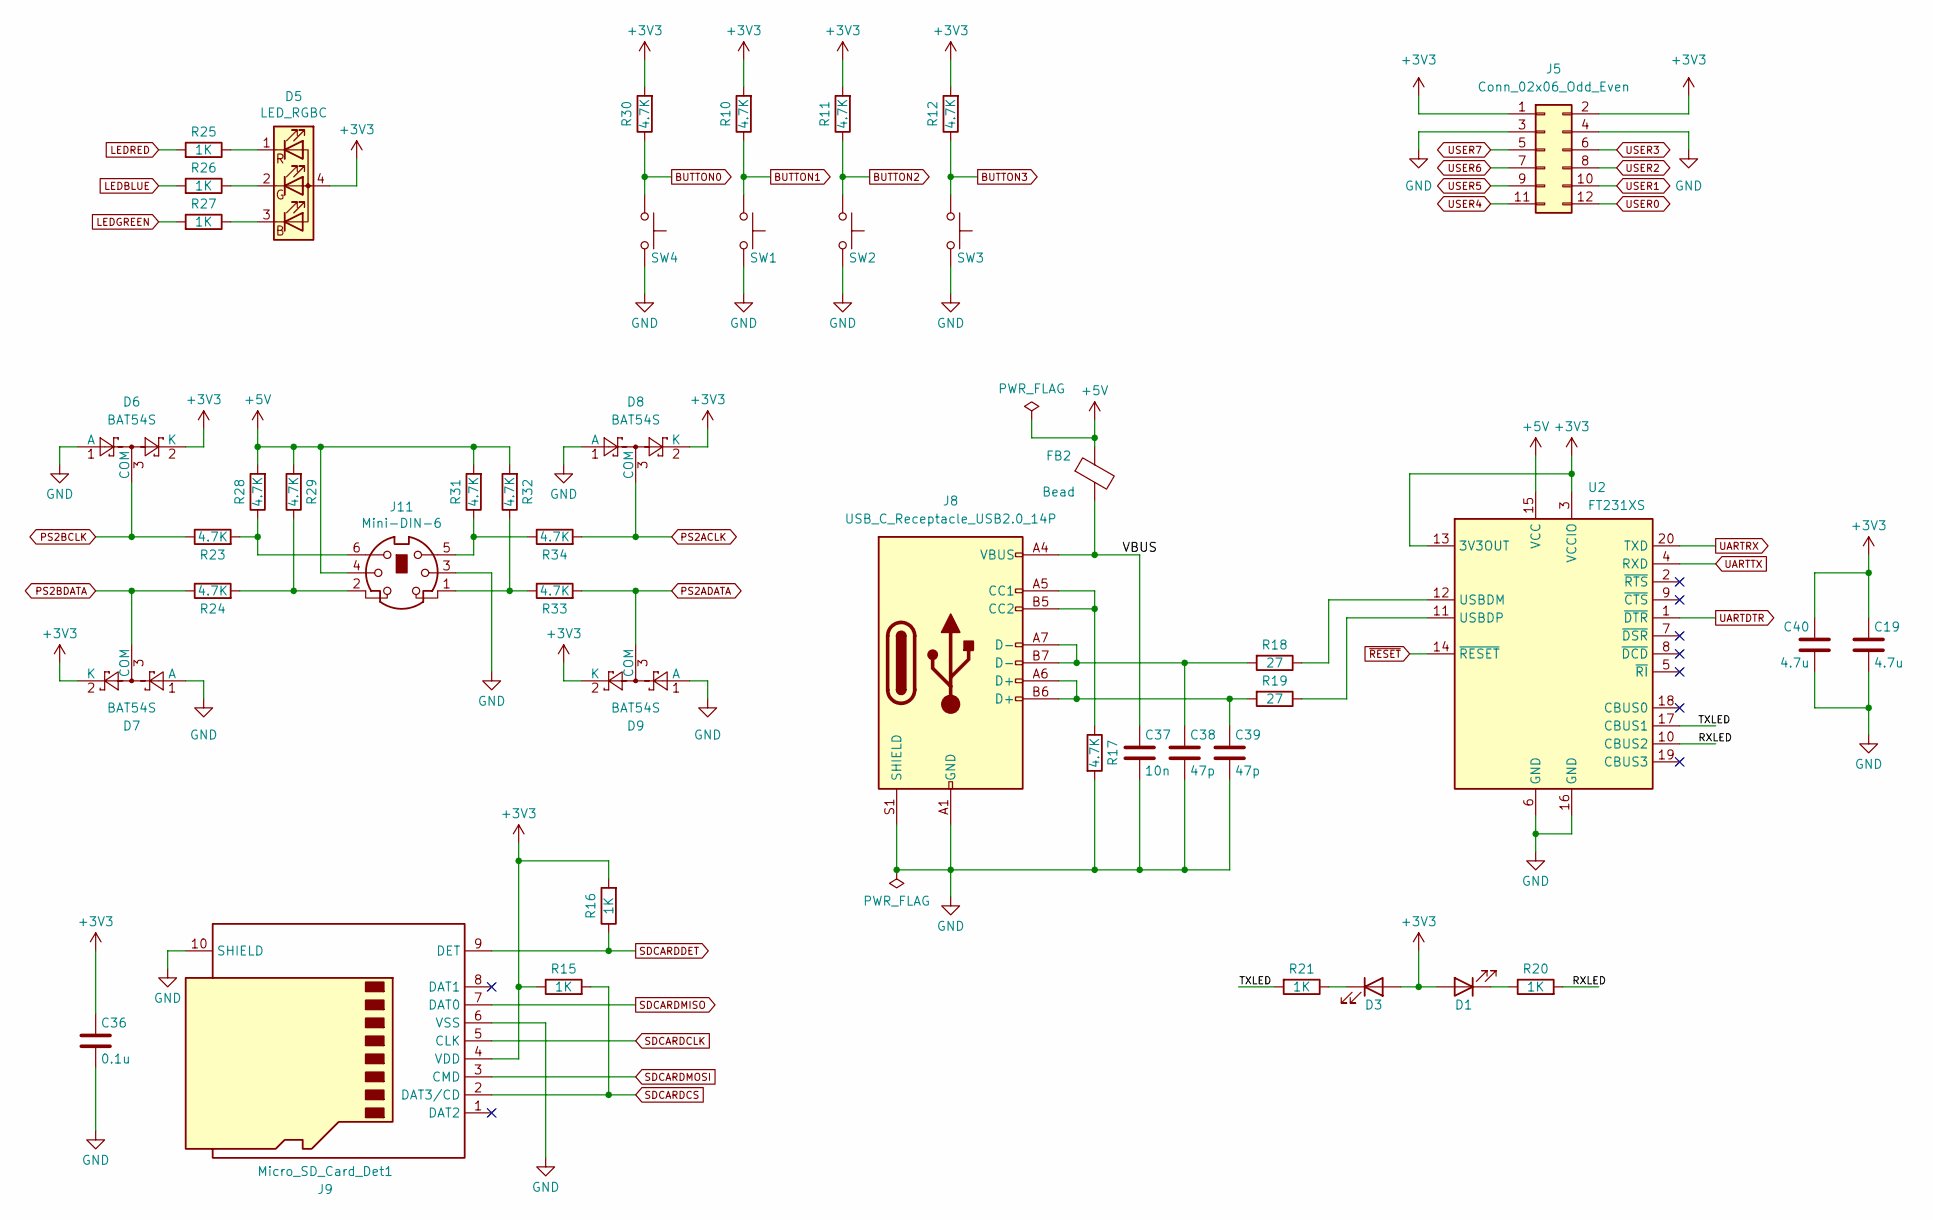
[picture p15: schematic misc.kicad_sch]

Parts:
C19, C40: 4.7u; C_0805_2012Metric
C36: 0.1u; C_0805_2012Metric
C37: 10n; C_0805_2012Metric
C38, C39: 47p; C_0805_2012Metric
D1, D3: UART_LED; LED_1210_3225Metric
D5: LED_RGBC; LED_Cree-PLCC4_3.2x2.8mm_CCW
D6, D7, D8, D9: BAT54S; SOT-23
FB2: Bead; L_1206_3216Metric
J5: Conn_02x06_Odd_Even; PinSocket_2x06_P2.54mm_Horizontal
J8: USB_C_Receptacle_USB2.0_14P; USB_C_Receptacle_GCT_USB4105-xx-A_16P_TopMnt_Horizontal
J9: Micro_SD_Card_Det1; microSD_HC_Hirose_DM3BT-DSF-PEJS
J11: Mini-DIN-6; Connector_Mini-DIN_Female_6Pin_2rows
R10, R11, R12, R17, R23, R24, R28, R29, R30, R31, R32, R33, R34: 4.7K; R_0805_2012Metric
R15, R16, R20, R21, R25, R26, R27: 1K; R_0805_2012Metric
R18, R19: 27; R_0805_2012Metric
SW1, SW2, SW3, SW4: BUTTON; SW_Push_1P1T_NO_CK_KSC6xxJ
U2: FT231XS; SSOP-20_3.9x8.7mm_P0.635mm

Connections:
+3V3: C19.1, C36.1, C40.1, D1.2 (A), D3.2 (A), D5.4 (A), D6.2 (K), D7.2 (K), D8.2 (K), D9.2 (K), J5.1, J5.2, J9.4 (VDD), R10.2, R11.2, R12.2, R15.1, R16.2, R30.2, U2.3 (VCCIO), U2.13 (3V3OUT); also elsewhere on the board
+5V: FB2.1, J11.4, R28.2, R29.2, R31.2, R32.2, U2.15 (VCC); also elsewhere on the board
/Misc/RXLED: R20.2, U2.10 (CBUS2)
/Misc/TXLED: R21.2, U2.17 (CBUS1)
/Misc/VBUS: C37.1, FB2.2, J8.A4 (VBUS), J8.A9 (VBUS), J8.B4 (VBUS), J8.B9 (VBUS)
BUTTON0: R30.1, SW4.1; also elsewhere on the board
BUTTON1: R10.1, SW1.1; also elsewhere on the board
BUTTON2: R11.1, SW2.1; also elsewhere on the board
BUTTON3: R12.1, SW3.1; also elsewhere on the board
GND: C19.2, C36.2, C37.2, C38.2, C39.2, C40.2, D6.1 (A), D7.1 (A), D8.1 (A), D9.1 (A), J5.3, J5.4, J8.A1 (GND), J8.A12 (GND), J8.B1 (GND), J8.B12 (GND), J8.S1 (SHIELD), J9.6 (VSS), J9.10 (SHIELD), J11.3, R17.2, SW1.2, SW2.2, SW3.2, SW4.2, U2.6 (GND), U2.16 (GND); also elsewhere on the board
LEDBLUE: R26.2; also elsewhere on the board
LEDGREEN: R27.2; also elsewhere on the board
LEDRED: R25.2; also elsewhere on the board
unnamed: C38.1, J8.A7 (D-), J8.B7 (D-), R18.2
unnamed: C39.1, J8.A6 (D+), J8.B6 (D+), R19.2
unnamed: D1.1 (K), R20.1
unnamed: D3.1 (K), R21.1
unnamed: D5.3 (BK), R27.1
unnamed: D5.2 (GK), R26.1
unnamed: D5.1 (RK), R25.1
unnamed: J8.A5 (CC1), J8.B5 (CC2), R17.1
unnamed: J11.1, R32.1, R33.1
unnamed: J11.2, R24.2, R29.1
unnamed: J11.5, R31.1, R34.1
unnamed: J11.6, R23.2, R28.1
unnamed: R18.1, U2.12 (USBDM)
unnamed: R19.1, U2.11 (USBDP)
PS2ACLK: D8.3 (COM), R34.2; also elsewhere on the board
PS2ADATA: D9.3 (COM), R33.2; also elsewhere on the board
PS2BCLK: D6.3 (COM), R23.1; also elsewhere on the board
PS2BDATA: D7.3 (COM), R24.1; also elsewhere on the board
SDCARDCLK: J9.5 (CLK); also elsewhere on the board
SDCARDCS: J9.2 (DAT3/CD), R15.2; also elsewhere on the board
SDCARDDET: J9.9 (DET), R16.1; also elsewhere on the board
SDCARDMISO: J9.7 (DAT0); also elsewhere on the board
SDCARDMOSI: J9.3 (CMD); also elsewhere on the board
UARTDTR: U2.1 (~DTR); also elsewhere on the board
UARTRX: U2.20 (TXD); also elsewhere on the board
UARTTX: U2.4 (RXD); also elsewhere on the board
USER0: J5.12; also elsewhere on the board
USER1: J5.10; also elsewhere on the board
USER2: J5.8; also elsewhere on the board
USER3: J5.6; also elsewhere on the board
USER4: J5.11; also elsewhere on the board
USER5: J5.9; also elsewhere on the board
USER6: J5.7; also elsewhere on the board
USER7: J5.5; also elsewhere on the board
~RESET: U2.14 (~RESET); also elsewhere on the board

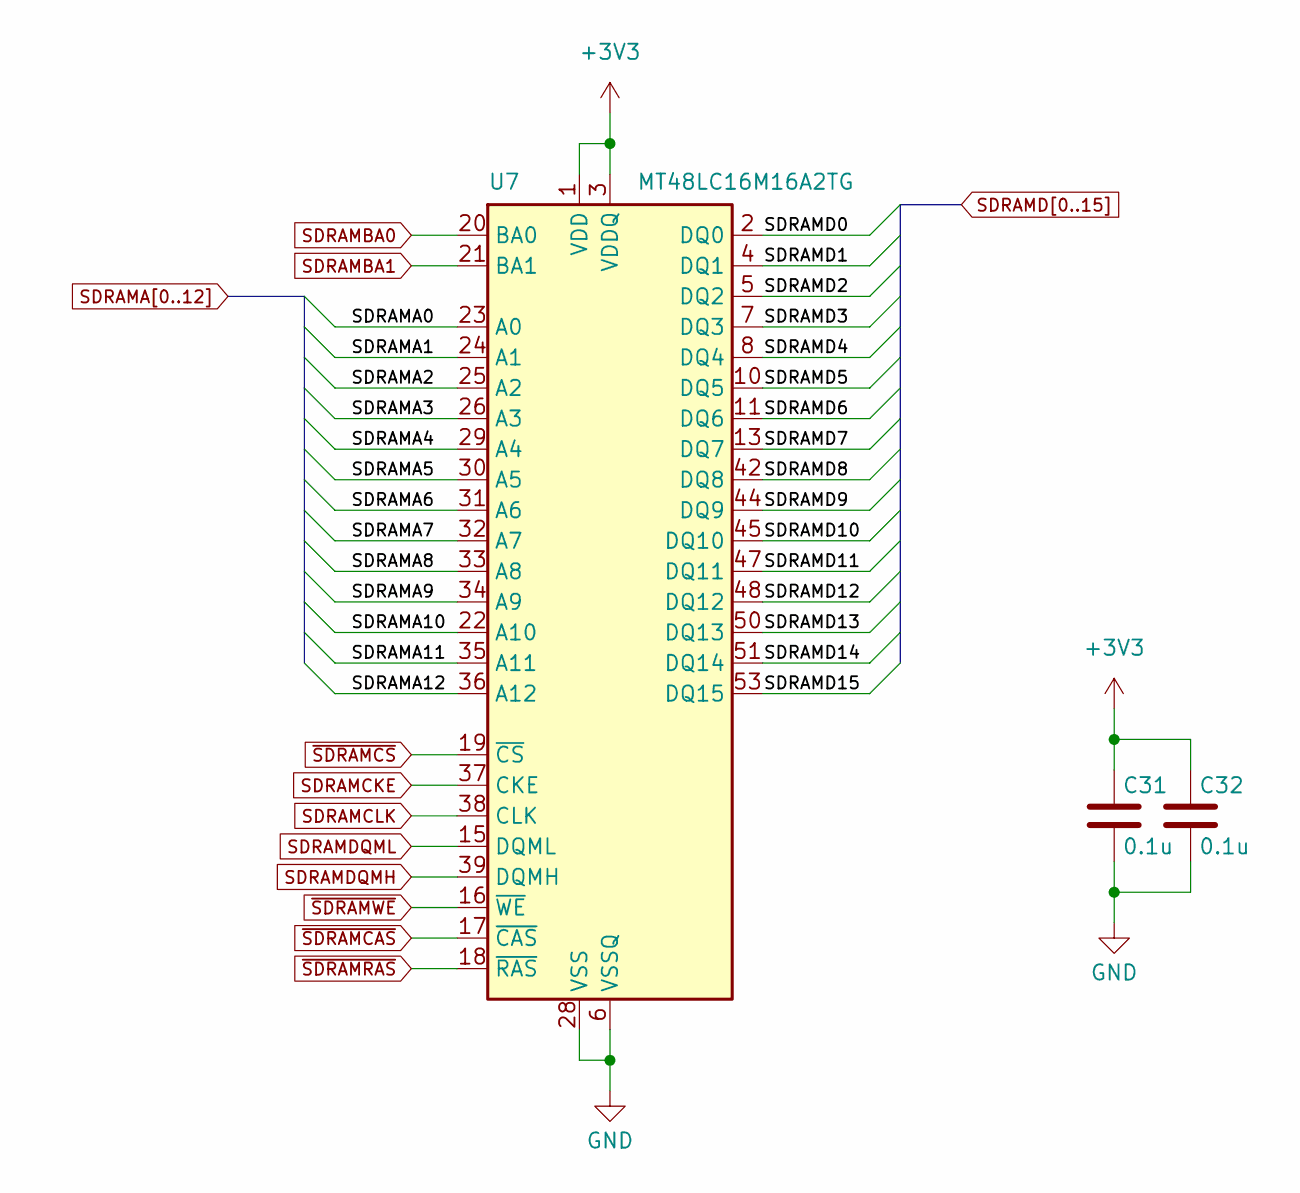
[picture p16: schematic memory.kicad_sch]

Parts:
C31, C32: 0.1u; C_0805_2012Metric
U7: MT48LC16M16A2TG; TSOP-II-54_22.2x10.16mm_P0.8mm

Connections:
+3V3: C31.1, C32.1, U7.1 (VDD), U7.3 (VDDQ), U7.9 (VDDQ), U7.14 (VDD), U7.27 (VDD), U7.43 (VDDQ), U7.49 (VDDQ); also elsewhere on the board
GND: C31.2, C32.2, U7.6 (VSSQ), U7.12 (VSSQ), U7.28 (VSS), U7.41 (VSS), U7.46 (VSSQ), U7.52 (VSSQ), U7.54 (VSS); also elsewhere on the board
SDRAMA0: U7.23 (A0); also elsewhere on the board
SDRAMA1: U7.24 (A1); also elsewhere on the board
SDRAMA2: U7.25 (A2); also elsewhere on the board
SDRAMA3: U7.26 (A3); also elsewhere on the board
SDRAMA4: U7.29 (A4); also elsewhere on the board
SDRAMA5: U7.30 (A5); also elsewhere on the board
SDRAMA6: U7.31 (A6); also elsewhere on the board
SDRAMA7: U7.32 (A7); also elsewhere on the board
SDRAMA8: U7.33 (A8); also elsewhere on the board
SDRAMA9: U7.34 (A9); also elsewhere on the board
SDRAMA10: U7.22 (A10); also elsewhere on the board
SDRAMA11: U7.35 (A11); also elsewhere on the board
SDRAMA12: U7.36 (A12); also elsewhere on the board
SDRAMBA0: U7.20 (BA0); also elsewhere on the board
SDRAMBA1: U7.21 (BA1); also elsewhere on the board
SDRAMCKE: U7.37 (CKE); also elsewhere on the board
SDRAMCLK: U7.38 (CLK); also elsewhere on the board
SDRAMD0: U7.2 (DQ0); also elsewhere on the board
SDRAMD1: U7.4 (DQ1); also elsewhere on the board
SDRAMD2: U7.5 (DQ2); also elsewhere on the board
SDRAMD3: U7.7 (DQ3); also elsewhere on the board
SDRAMD4: U7.8 (DQ4); also elsewhere on the board
SDRAMD5: U7.10 (DQ5); also elsewhere on the board
SDRAMD6: U7.11 (DQ6); also elsewhere on the board
SDRAMD7: U7.13 (DQ7); also elsewhere on the board
SDRAMD8: U7.42 (DQ8); also elsewhere on the board
SDRAMD9: U7.44 (DQ9); also elsewhere on the board
SDRAMD10: U7.45 (DQ10); also elsewhere on the board
SDRAMD11: U7.47 (DQ11); also elsewhere on the board
SDRAMD12: U7.48 (DQ12); also elsewhere on the board
SDRAMD13: U7.50 (DQ13); also elsewhere on the board
SDRAMD14: U7.51 (DQ14); also elsewhere on the board
SDRAMD15: U7.53 (DQ15); also elsewhere on the board
SDRAMDQMH: U7.39 (DQMH); also elsewhere on the board
SDRAMDQML: U7.15 (DQML); also elsewhere on the board
~SDRAMCAS: U7.17 (~CAS); also elsewhere on the board
~SDRAMCS: U7.19 (~CS); also elsewhere on the board
~SDRAMRAS: U7.18 (~RAS); also elsewhere on the board
~SDRAMWE: U7.16 (~WE); also elsewhere on the board

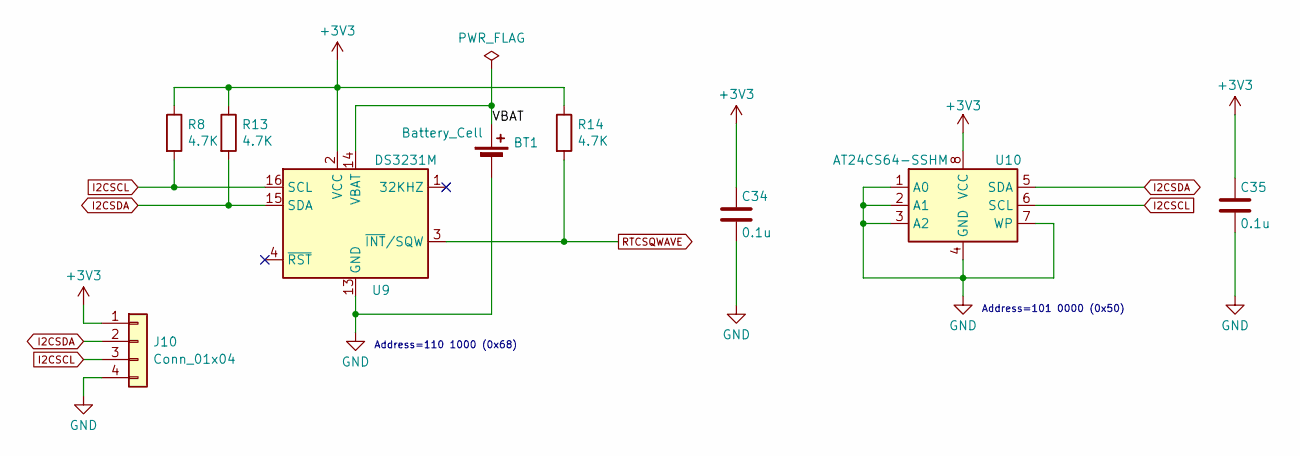
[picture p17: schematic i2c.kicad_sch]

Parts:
BT1: Battery_Cell; BatteryHolder_Keystone_3000_1x12mm
C34, C35: 0.1u; C_0805_2012Metric
J10: Conn_01x04; PinHeader_1x04_P2.54mm_Vertical
R8, R13, R14: 4.7K; R_0805_2012Metric
U9: DS3231M; SOIC-16W_7.5x10.3mm_P1.27mm
U10: AT24CS64-SSHM; SOIC-8_3.9x4.9mm_P1.27mm

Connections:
+3V3: C34.1, C35.1, J10.1, R8.1, R13.1, R14.1, U9.2 (VCC), U10.8 (VCC); also elsewhere on the board
/I2C/VBAT: BT1.1 (+), U9.14 (VBAT)
GND: BT1.2 (-), C34.2, C35.2, J10.4, U9.5 (GND), U9.6 (GND), U9.7 (GND), U9.8 (GND), U9.9 (GND), U9.10 (GND), U9.11 (GND), U9.12 (GND), U9.13 (GND), U10.1 (A0), U10.2 (A1), U10.3 (A2), U10.4 (GND), U10.7 (WP); also elsewhere on the board
I2CSCL: J10.3, R8.2, U9.16 (SCL), U10.6 (SCL); also elsewhere on the board
I2CSDA: J10.2, R13.2, U9.15 (SDA), U10.5 (SDA); also elsewhere on the board
RTCSQWAVE: R14.2, U9.3 (~INT/SQW); also elsewhere on the board

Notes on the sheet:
Address=110 1000 (0x68)
Address=101 0000 (0x50)

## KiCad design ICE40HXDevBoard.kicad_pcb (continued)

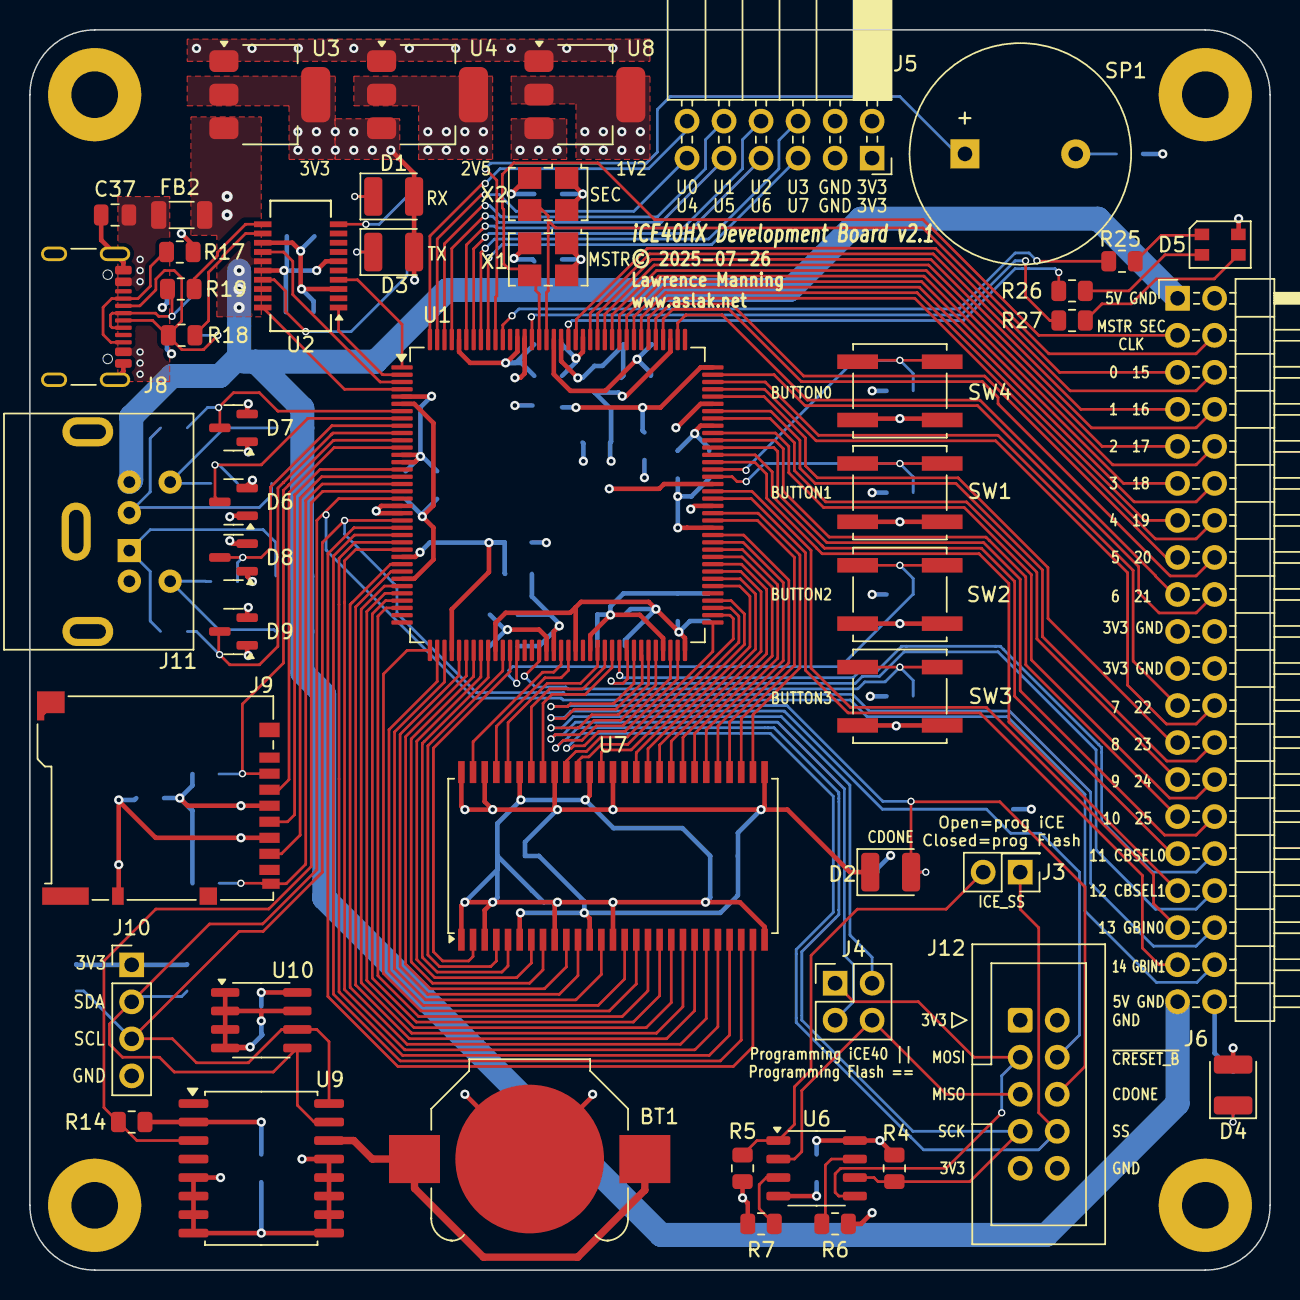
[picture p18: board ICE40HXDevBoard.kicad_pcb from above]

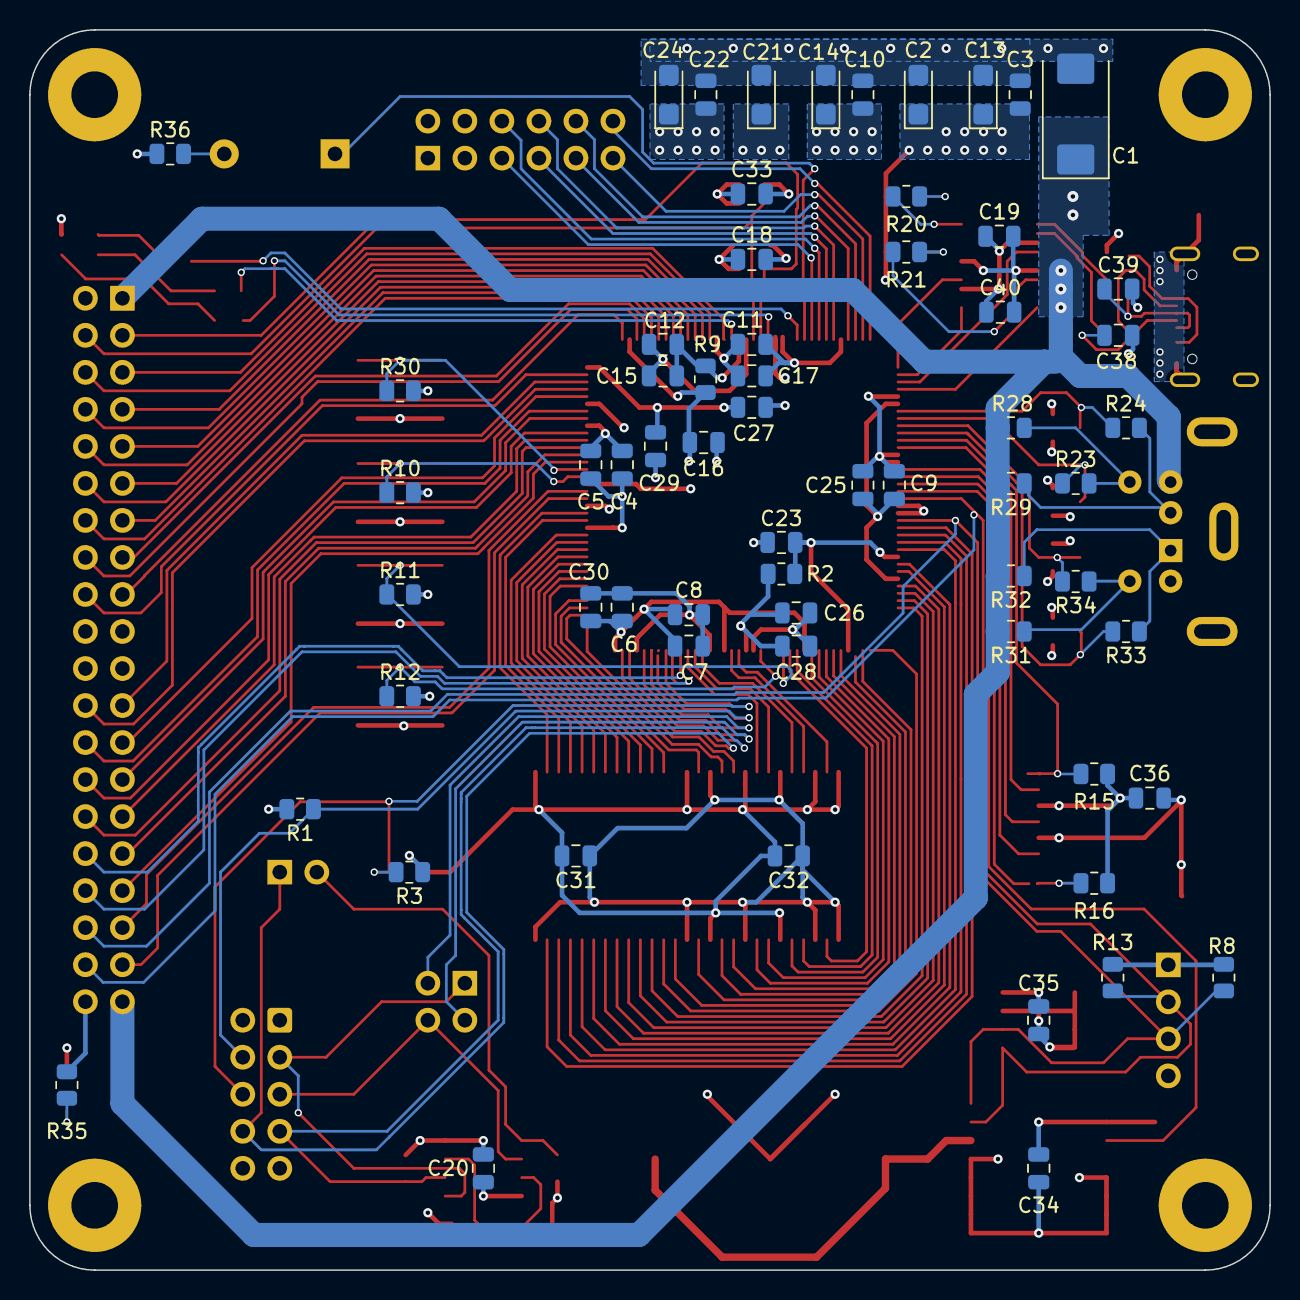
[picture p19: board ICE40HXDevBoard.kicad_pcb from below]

Board: 4 copper layers, 85.1 x 85.1 mm, 115 parts (63 on the bottom side), 141 nets.

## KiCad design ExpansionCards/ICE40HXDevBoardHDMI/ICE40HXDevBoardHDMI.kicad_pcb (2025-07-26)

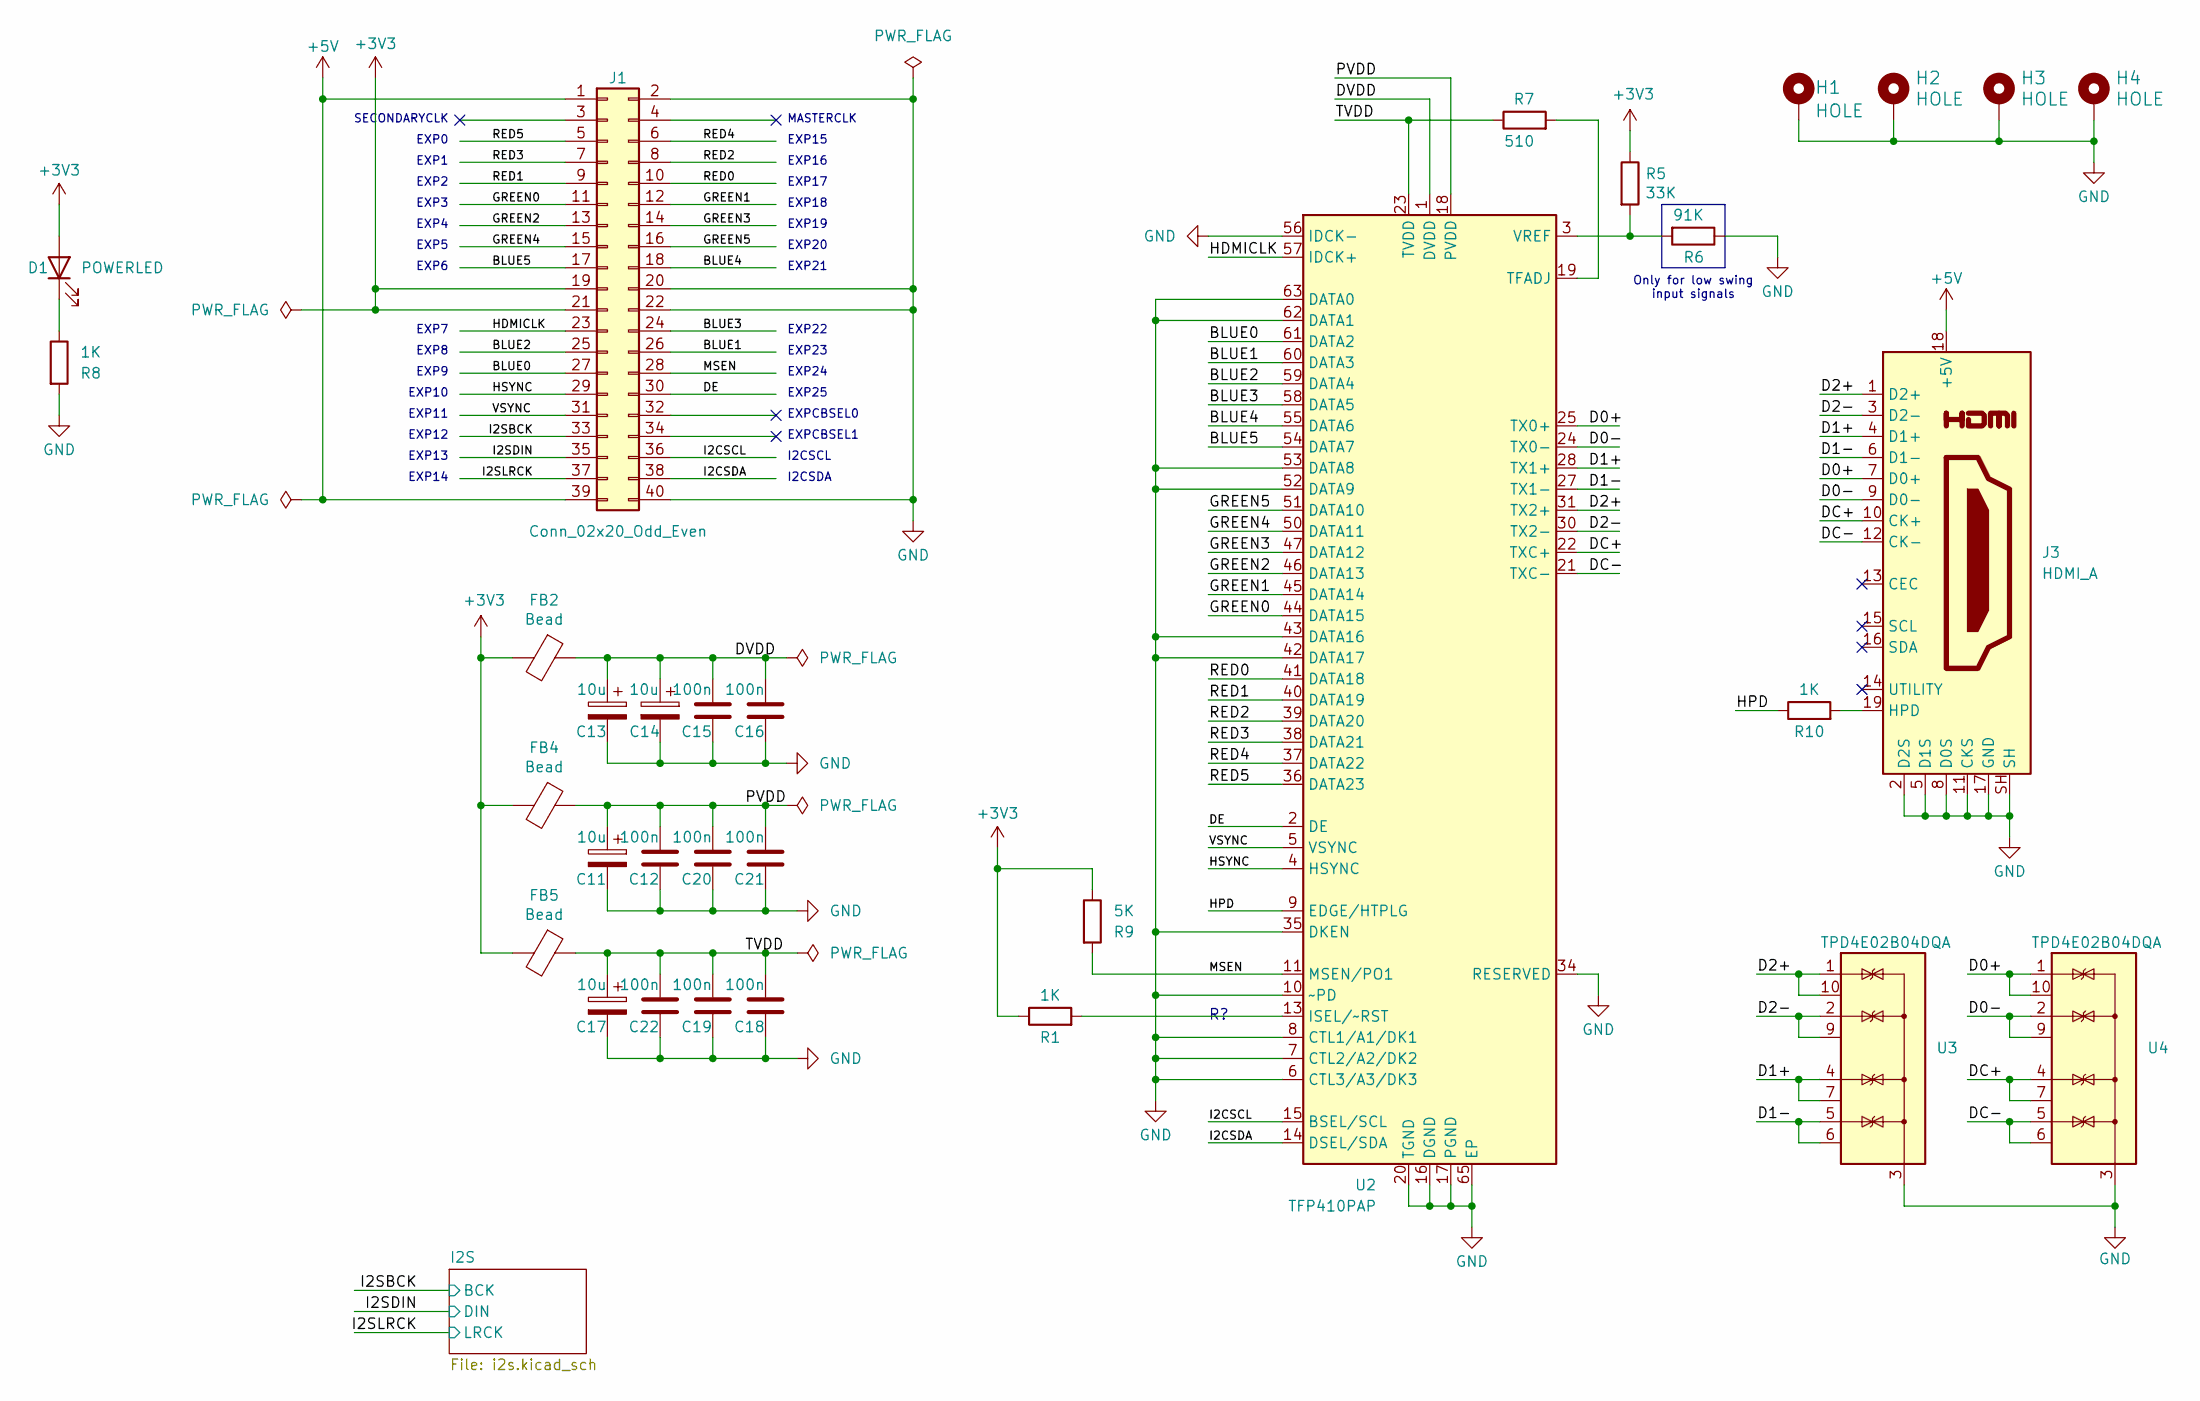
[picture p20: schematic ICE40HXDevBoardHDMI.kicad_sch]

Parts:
C11, C13, C14, C17: 10u; CP_EIA-3216-18_Kemet-A
C12, C15, C16, C18, C19, C20, C21, C22: 100n; C_0603_1608Metric
D1: POWERLED; LED_1210_3225Metric
FB2, FB4, FB5: Bead; L_0805_2012Metric
H1, H2, H3, H4: HOLE; MountingHole_3.2mm_M3_Pad
J1: Conn_02x20_Odd_Even; PinSocket_2x20_P2.54mm_Horizontal
J3: HDMI_A; HDMI_A_Molex_208658-1001_Horizontal
R1, R8, R10: 1K; R_0805_2012Metric
R5: 33K; R_0805_2012Metric
R6: 91K; R_0805_2012Metric
R7: 510; R_0805_2012Metric
R9: 5K; R_0805_2012Metric
U2: TFP410PAP; LQFP-64-1EP_10x10mm_P0.5mm_EP5x5mm_ThermalVias; MPN TFP410PAP; LCSC Part # C1543847
U3, U4: TPD4E02B04DQA; USON-10_2.5x1.0mm_P0.5mm

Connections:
+3V3: D1.2 (A), FB2.2, FB4.2, FB5.2, J1.19, J1.21, R1.1, R5.1, R9.1; also elsewhere on the board
+5V: J1.1, J1.39, J3.18 (+5V)
/BLUE0: J1.27, U2.61 (DATA2)
/BLUE1: J1.26, U2.60 (DATA3)
/BLUE2: J1.25, U2.59 (DATA4)
/BLUE3: J1.24, U2.58 (DATA5)
/BLUE4: J1.18, U2.55 (DATA6)
/BLUE5: J1.17, U2.54 (DATA7)
/D0+: J3.7 (D0+), U2.25 (TX0+), U4.1 (IO1), U4.10 (NC)
/D0-: J3.9 (D0-), U2.24 (TX0-), U4.2 (IO2), U4.9 (NC)
/D1+: J3.4 (D1+), U2.28 (TX1+), U3.4 (IO3), U3.7 (NC)
/D1-: J3.6 (D1-), U2.27 (TX1-), U3.5 (IO4), U3.6 (NC)
/D2+: J3.1 (D2+), U2.31 (TX2+), U3.1 (IO1), U3.10 (NC)
/D2-: J3.3 (D2-), U2.30 (TX2-), U3.2 (IO2), U3.9 (NC)
/DC+: J3.10 (CK+), U2.22 (TXC+), U4.4 (IO3), U4.7 (NC)
/DC-: J3.12 (CK-), U2.21 (TXC-), U4.5 (IO4), U4.6 (NC)
/DE: J1.30, U2.2 (DE)
/DVDD: C13.1, C14.1, C15.1, C16.1, FB2.1, U2.1 (DVDD), U2.12 (DVDD), U2.33 (DVDD)
/GREEN0: J1.11, U2.44 (DATA15)
/GREEN1: J1.12, U2.45 (DATA14)
/GREEN2: J1.13, U2.46 (DATA13)
/GREEN3: J1.14, U2.47 (DATA12)
/GREEN4: J1.15, U2.50 (DATA11)
/GREEN5: J1.16, U2.51 (DATA10)
/HDMICLK: J1.23, U2.57 (IDCK+)
/HPD: R10.1, U2.9 (EDGE/HTPLG)
/HSYNC: J1.29, U2.4 (HSYNC)
/I2CSCL: J1.36, U2.15 (BSEL/SCL)
/I2CSDA: J1.38, U2.14 (DSEL/SDA)
/I2SBCK: J1.33; also elsewhere on the board
/I2SDIN: J1.35; also elsewhere on the board
/I2SLRCK: J1.37; also elsewhere on the board
/MSEN: J1.28, R9.2, U2.11 (MSEN/PO1)
/PVDD: C11.1, C12.1, C20.1, C21.1, FB4.1, U2.18 (PVDD)
/RED0: J1.10, U2.41 (DATA18)
/RED1: J1.9, U2.40 (DATA19)
/RED2: J1.8, U2.39 (DATA20)
/RED3: J1.7, U2.38 (DATA21)
/RED4: J1.6, U2.37 (DATA22)
/RED5: J1.5, U2.36 (DATA23)
/TVDD: C17.1, C18.1, C19.1, C22.1, FB5.1, R7.1, U2.23 (TVDD), U2.29 (TVDD)
/VSYNC: J1.31, U2.5 (VSYNC)
GND: C11.2, C12.2, C13.2, C14.2, C15.2, C16.2, C17.2, C18.2, C19.2, C20.2, C21.2, C22.2, H1.1, H2.1, H3.1, H4.1, J1.2, J1.20, J1.22, J1.40, J3.2 (D2S), J3.5 (D1S), J3.8 (D0S), J3.11 (CKS), J3.17 (GND), J3.SH, R6.1, R8.2, U2.6 (CTL3/A3/DK3), U2.7 (CTL2/A2/DK2), U2.8 (CTL1/A1/DK1), U2.10 (~PD), U2.16 (DGND), U2.17 (PGND), U2.20 (TGND), U2.26 (TGND), U2.32 (TGND), U2.34 (RESERVED), U2.35 (DKEN), U2.42 (DATA17), U2.43 (DATA16), U2.48 (DGND), U2.52 (DATA9), U2.53 (DATA8), U2.56 (IDCK-), U2.62 (DATA1), U2.63 (DATA0), U2.64 (DGND), U2.65 (EP), U3.3 (G), U3.8 (G), U4.3 (G), U4.8 (G); also elsewhere on the board
unnamed: D1.1 (K), R8.1
unnamed: J3.19 (HPD), R10.2
unnamed: R1.2, U2.13 (ISEL/~RST)
unnamed: R7.2, U2.19 (TFADJ)
unnamed: R5.2, R6.2, U2.3 (VREF)

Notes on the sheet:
EXP13
EXP8
EXP24
EXP16
EXP4
EXP3
EXP14
EXP20
EXP23
EXP22
EXP5
Only for low swing input signals
EXP1
I2CSDA
EXP6
EXP2
EXP0
SECONDARYCLK
EXP25
MASTERCLK
EXP11
EXP9
EXP10
EXPCBSEL0
EXP15
EXP17
EXP19
EXPCBSEL1
EXP7
I2CSCL
EXP12
EXP18
EXP21

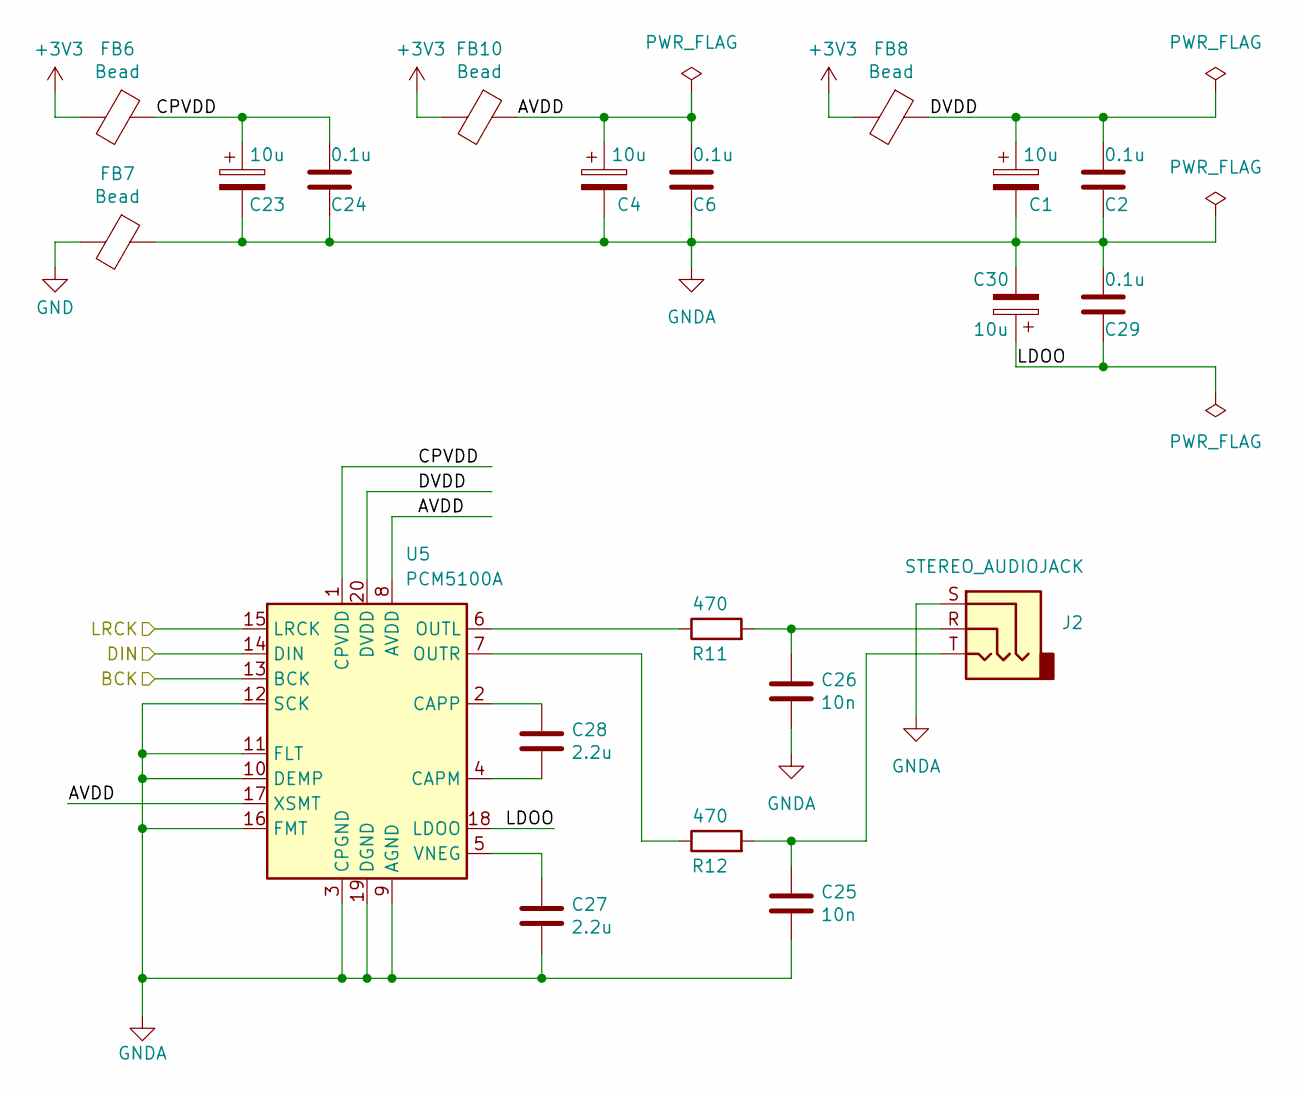
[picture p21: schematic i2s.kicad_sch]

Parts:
C1, C4, C23, C30: 10u; CP_EIA-3216-18_Kemet-A
C2, C6, C24, C29: 0.1u; C_0805_2012Metric
C25, C26: 10n; C_0805_2012Metric
C27, C28: 2.2u; C_0805_2012Metric
FB6, FB7, FB8, FB10: Bead; L_1206_3216Metric
J2: STEREO_AUDIOJACK; Jack_3.5mm_Switronic_ST-005-G_horizontal
R11, R12: 470; R_0805_2012Metric
U5: PCM5100A; TSSOP-20_4.4x6.5mm_P0.65mm

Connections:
+3V3: FB6.2, FB8.2, FB10.2; also elsewhere on the board
/I2S/AVDD: C4.1, C6.1, FB10.1, U5.8 (AVDD), U5.17 (XSMT)
/I2S/CPVDD: C23.1, C24.1, FB6.1, U5.1 (CPVDD)
/I2S/DVDD: C1.1, C2.1, FB8.1, U5.20 (DVDD)
/I2S/LDOO: C29.2, C30.1, U5.18 (LDOO)
/I2SBCK: U5.13 (BCK); also elsewhere on the board
/I2SDIN: U5.14 (DIN); also elsewhere on the board
/I2SLRCK: U5.15 (LRCK); also elsewhere on the board
GND: FB7.2; also elsewhere on the board
GNDA: C1.2, C2.2, C4.2, C6.2, C23.2, C24.2, C25.2, C26.2, C27.2, C29.1, C30.2, FB7.1, J2.S, U5.3 (CPGND), U5.9 (AGND), U5.10 (DEMP), U5.11 (FLT), U5.12 (SCK), U5.16 (FMT), U5.19 (DGND)
unnamed: C25.1, J2.T, R12.2
unnamed: C26.1, J2.R, R11.2
unnamed: C28.2, U5.4 (CAPM)
unnamed: C28.1, U5.2 (CAPP)
unnamed: R11.1, U5.6 (OUTL)
unnamed: R12.1, U5.7 (OUTR)
unnamed: C27.1, U5.5 (VNEG)

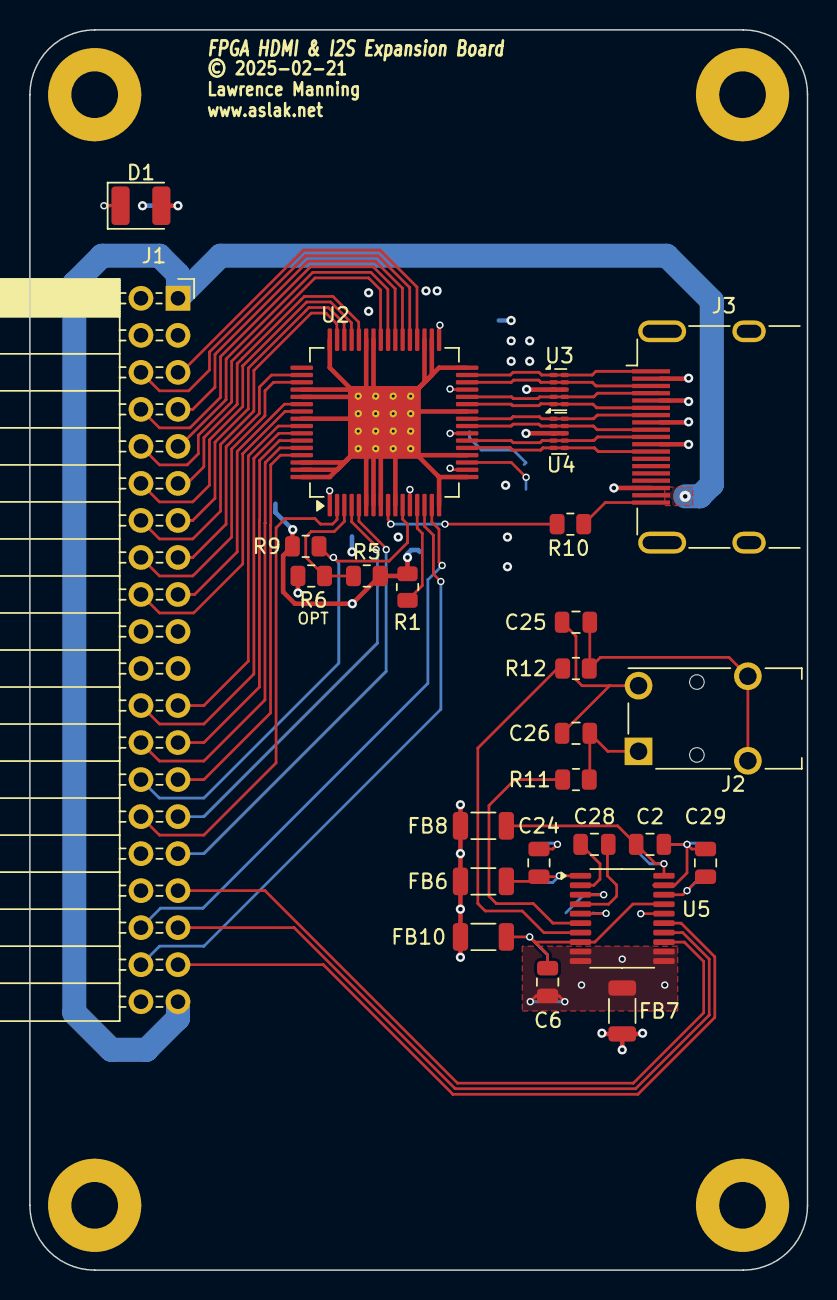
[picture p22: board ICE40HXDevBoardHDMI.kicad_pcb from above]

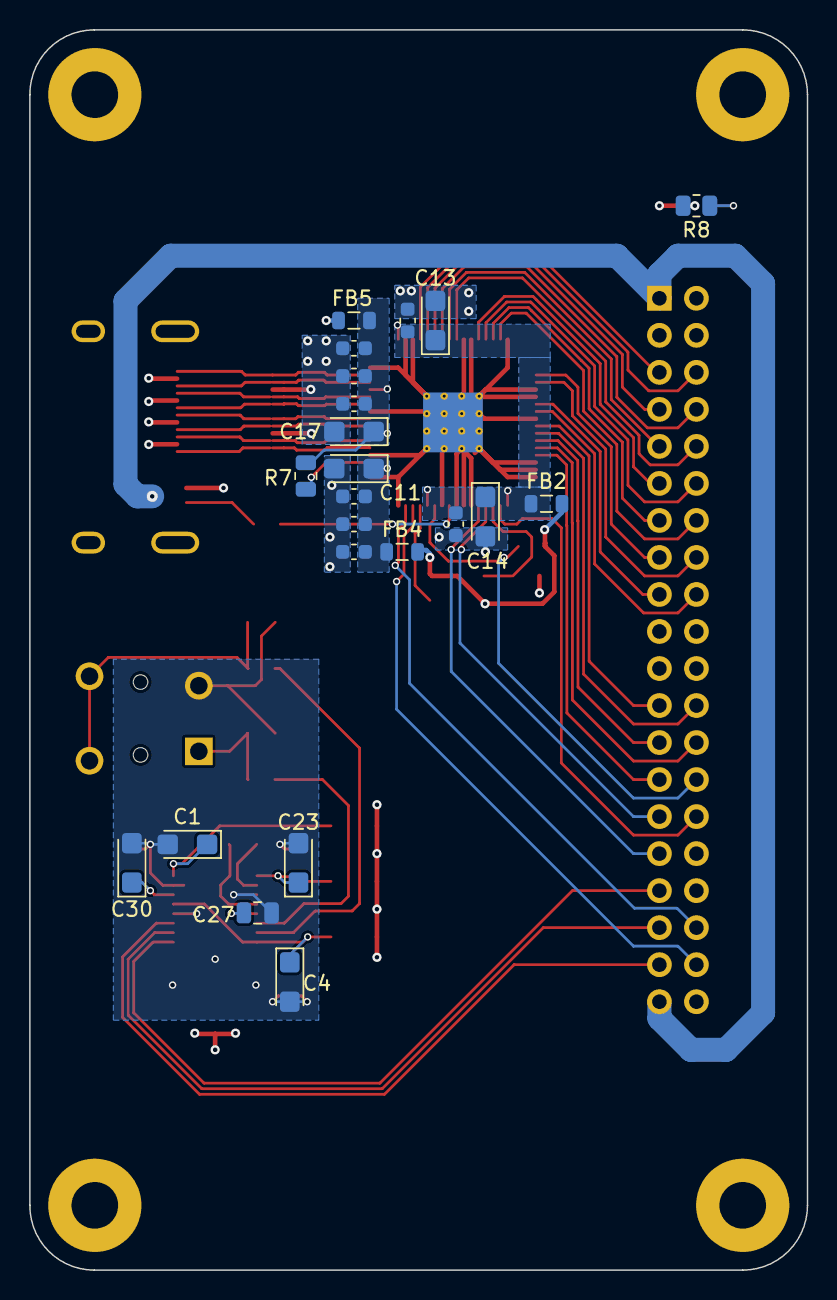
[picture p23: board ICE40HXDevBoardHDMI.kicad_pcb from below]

Board: 4 copper layers, 53.4 x 85.1 mm, 52 parts (22 on the bottom side), 60 nets.

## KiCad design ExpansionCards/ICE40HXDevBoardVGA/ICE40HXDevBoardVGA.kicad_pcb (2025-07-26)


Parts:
C1, C2, C3: 0.1u; C_0805_2012Metric
D1: POWERLED; LED_1210_3225Metric
FB1: Bead; L_1206_3216Metric
H1, H2, H3, H4: HOLE; MountingHole_3.2mm_M3_Pad
J1: Conn_02x20_Odd_Even; PinSocket_2x20_P2.54mm_Horizontal
J2: DB15HD_FEMALE_SVGA; DSUB-15-HD_Female_Horizontal_P2.29x1.90mm_EdgePinOffset3.03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
R1, R3, R4: 75; R_0805_2012Metric
R2: 530; R_0805_2012Metric
R5: 4.7K; R_0805_2012Metric
R6, R7: 47; R_0805_2012Metric
R12: 1K; R_0805_2012Metric
U1: ADV7123KSTZ140; LQFP-48_7x7mm_P0.5mm

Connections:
+3.3VDAC: C1.2, C2.2, C3.1, FB1.1, R5.1, U1.13 (VAA), U1.29 (VAA), U1.30 (VAA)
+3V3: D1.2 (A), FB1.2, J1.19, J1.21; also elsewhere on the board
+5V: J1.1, J1.39
/BLUE: J2.3, R4.1, U1.28 (IOB)
/BLUE0: J1.18, U1.18 (B4)
/BLUE1: J1.23, U1.19 (B5)
/BLUE2: J1.24, U1.20 (B6)
/BLUE3: J1.25, U1.21 (B7)
/BLUE4: J1.26, U1.22 (B8)
/BLUE5: J1.27, U1.23 (B9)
/DACCLK: J1.28, U1.24 (CLOCK)
/GREEN: J2.2, R3.1, U1.32 (IOG)
/GREEN0: J1.11, U1.5 (G4)
/GREEN1: J1.12, U1.6 (G5)
/GREEN2: J1.13, U1.7 (G6)
/GREEN3: J1.14, U1.8 (G7)
/GREEN4: J1.15, U1.9 (G8)
/GREEN5: J1.16, U1.10 (G9)
/HSYNC: J1.31, R6.1
/I2SBCK: J1.33; also elsewhere on the board
/I2SDIN: J1.35; also elsewhere on the board
/I2SLRCK: J1.37; also elsewhere on the board
/I2SMUTE: J1.30
/RED: J2.1, R1.1, U1.34 (IOR)
/RED0: J1.5, U1.43 (R4)
/RED1: J1.6, U1.44 (R5)
/RED2: J1.7, U1.45 (R6)
/RED3: J1.8, U1.46 (R7)
/RED4: J1.9, U1.47 (R8)
/RED5: J1.10, U1.48 (R9)
/VSYNC: J1.29, R7.1
/~VGABLANK: J1.17, U1.11 (~BLANK)
GND: C3.2, H1.1, H2.1, H3.1, H4.1, J1.2, J1.20, J1.22, J1.40, J2.0, J2.5, J2.6, J2.7, J2.8, J2.10, R1.2, R2.2, R3.2, R4.2, R12.2, U1.1 (G0), U1.2 (G1), U1.3 (G2), U1.4 (G3), U1.12 (~SYNC), U1.14 (B0), U1.15 (B1), U1.16 (B2), U1.17 (B3), U1.25 (GND), U1.26 (GND), U1.27 (~IOB), U1.31 (~IOG), U1.33 (~IOR), U1.39 (R0), U1.40 (R1), U1.41 (R2), U1.42 (R3); also elsewhere on the board
unnamed: D1.1 (K), R12.1
unnamed: J2.13, R6.2
unnamed: J2.14, R7.2
unnamed: C1.1, U1.35 (COMP)
unnamed: R2.1, U1.37 (RSET)
unnamed: C2.1, U1.36 (VREF)
unnamed: R5.2, U1.38 (~PSAVE)

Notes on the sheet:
EXP13
EXP8
EXP24
EXP16
EXP4
EXP3
EXP14
EXP20
EXP23
EXP22
EXP5
EXP1
I2CSDA
EXP6
EXP2
EXP0
SECONDARYCLK
EXP25
MASTERCLK
EXP11
EXP9
EXP10
EXPCBSEL0
EXP15
EXP17
EXP19
EXPCBSEL1
EXP7
I2CSCL
EXP12
EXP18
EXP21


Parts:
C4, C8, C12, C13: 10u; CP_EIA-3216-18_Kemet-A
C5, C9, C14, C15: 0.1u; C_0805_2012Metric
C6, C7: 2.2u; C_0805_2012Metric
C10, C11: 10n; C_0805_2012Metric
FB2, FB3, FB4, FB5: Bead; L_1206_3216Metric
J3: STEREO_AUDIOJACK; Jack_3.5mm_Switronic_ST-005-G_horizontal
R8, R9: 470; R_0805_2012Metric
U2: PCM5100A; TSSOP-20_4.4x6.5mm_P0.65mm

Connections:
+3V3: FB2.2, FB4.2, FB5.2; also elsewhere on the board
/I2S/AVDD: C8.1, C9.1, FB4.1, U2.8 (AVDD), U2.17 (XSMT)
/I2S/CPVDD: C4.1, C5.1, FB2.1, U2.1 (CPVDD)
/I2S/DVDD: C12.1, C14.1, FB5.1, U2.20 (DVDD)
/I2S/LDOO: C13.1, C15.2, U2.18 (LDOO)
/I2SBCK: U2.13 (BCK); also elsewhere on the board
/I2SDIN: U2.14 (DIN); also elsewhere on the board
/I2SLRCK: U2.15 (LRCK); also elsewhere on the board
GND: FB3.2; also elsewhere on the board
GNDA: C4.2, C5.2, C7.2, C8.2, C9.2, C10.2, C11.2, C12.2, C13.2, C14.2, C15.1, FB3.1, J3.S, U2.3 (CPGND), U2.9 (AGND), U2.10 (DEMP), U2.11 (FLT), U2.12 (SCK), U2.16 (FMT), U2.19 (DGND)
unnamed: C10.1, J3.R, R8.2
unnamed: C11.1, J3.T, R9.2
unnamed: C6.2, U2.4 (CAPM)
unnamed: C6.1, U2.2 (CAPP)
unnamed: R8.1, U2.6 (OUTL)
unnamed: R9.1, U2.7 (OUTR)
unnamed: C7.1, U2.5 (VNEG)



Board: 4 copper layers, 40.6 x 85.1 mm, 40 parts (12 on the bottom side), 51 nets.

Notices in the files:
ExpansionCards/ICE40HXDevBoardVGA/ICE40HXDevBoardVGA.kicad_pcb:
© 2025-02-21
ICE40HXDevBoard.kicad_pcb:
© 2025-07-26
